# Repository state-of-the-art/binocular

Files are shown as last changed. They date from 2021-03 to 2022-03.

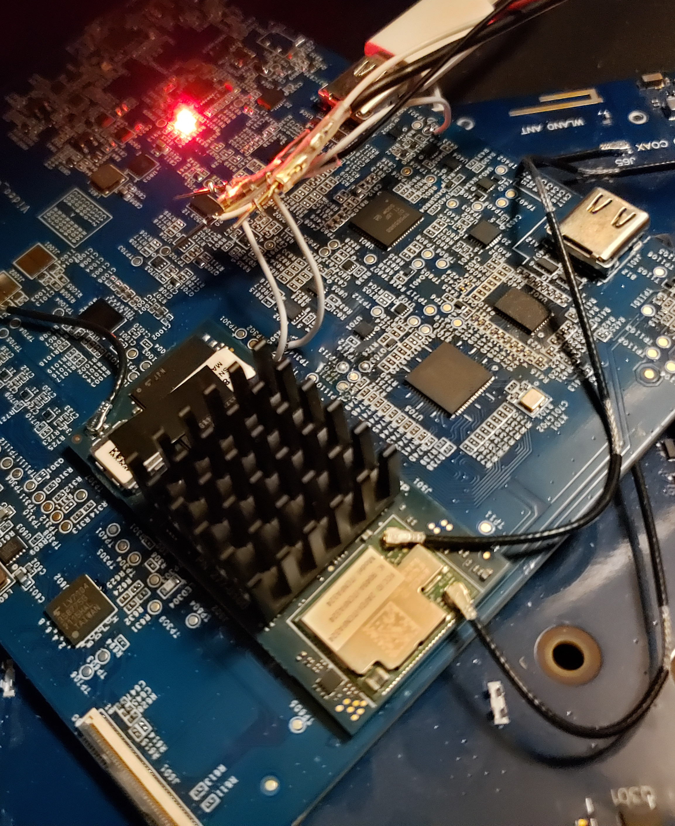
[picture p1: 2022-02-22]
design/prototype_1/pics/02_uart_boot_01_fail.jpg

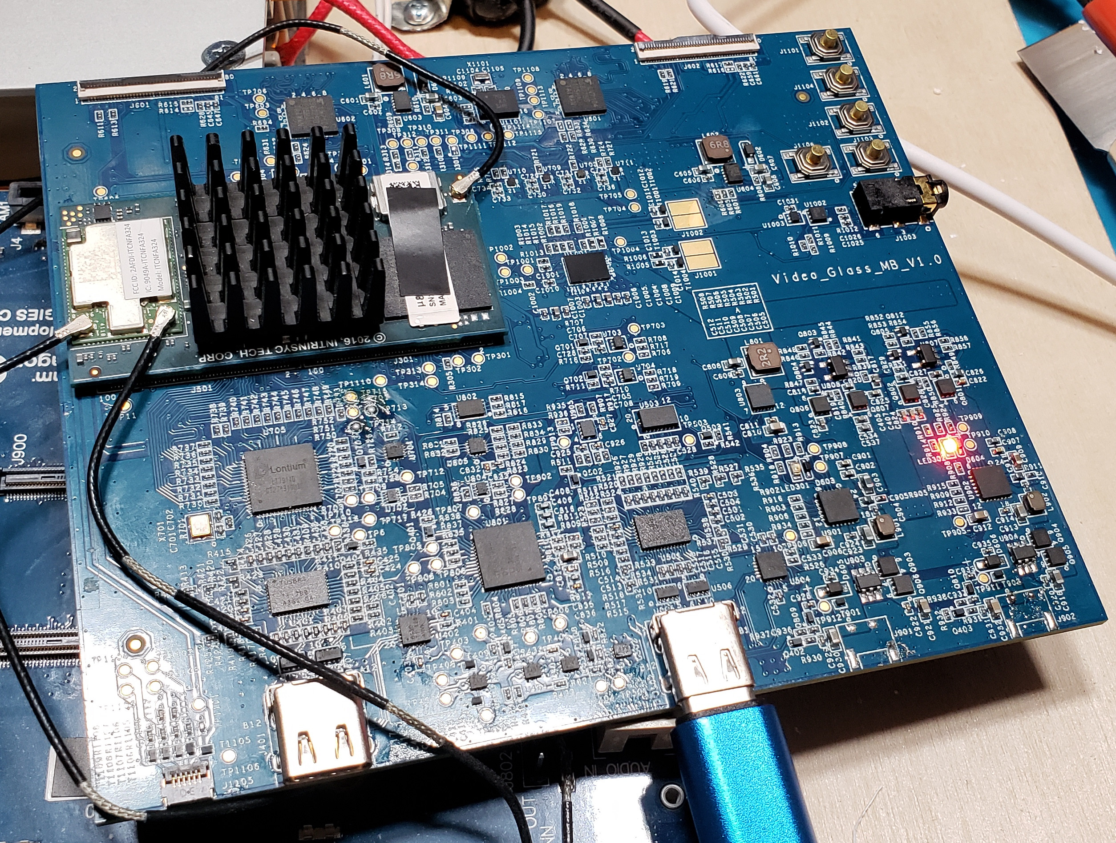
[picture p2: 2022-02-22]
design/prototype_1/pics/01_smoke_check.jpg

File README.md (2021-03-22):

# Binocular

Project aims to design the open hardware binocular wearing computer platform. It's PCB design and
the related software should be open to drive the development of VR/AR glasses for masses.

## Project Goal

To speedup the future come, where AR is a necessary part of the regular reality, like internet now.

## Designs

* [Prototype 1](design/prototype_1)

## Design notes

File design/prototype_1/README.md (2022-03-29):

# Prototype 1

The first prototype with the custom PCB design to fuse the SOM and modules together. Basically it
contains a number of buttons, leds, dual USB-C interface and a way to put SOM in place and connect
the displays.

## Requirements

1. Open Source and Open Hardware platform for light-weight wearable stereo displays as close as
currently possible to the regular glasses
2. No AR-grade positioning detection - just good quality high resolution see-through displays
(1920x1080)
3. Wireless (WiFi ac, h264/h265, battery power) and direct drive (USB-C DP alt-mode)

## Components

* [Platform](../../platform/snapdragon_820/open-q-u820/) - Open-Q µSOM 820
   * SOC - Snapdragon 820
* [Modules](../../modules/enmesi/r6) - Enmesi R6
  Birdbath (the best weight/quality ratio for now)
   * Displays - Sony ECX335S
* [PCB](pcb) - where SOM & Modules are met
* [Frame](frame) - TODO

## Documents

* [Design Document](Design Document.pdf)

## Configuring

In order to make Open-Q µSOM 820 work on the prototype - it should have a specific rpm partition
with modified LDO voltages. For this purpose it's better to get the original rpm partition from the
board, alter it's binary structure to write the required values into the special structure, resign
it and write back to the board.

To do that it's needed to have the original devboard for the prototype test board. Prototype release
will support protection for the used rails and will allow to flash any µSOM to the needed state.

**WARNING**: this is dangerous - writing the low-level partitions and especially altering them could
make your µSOM and devboard not bootable with common methods (only by EDL recovery), and the
operation we're going to do will make the µSOM not to work with devboard until the partition will
be restored. So you know - as is.

### Get with ADB

You can receive the rpm partition with root ADB.

1. Connect your devboard to power source
2. Connect the `USB2.0 (ADB)` to you host computer
3. Boot the devboard to android by pressing `ON/OFF` button
4. When the board boot-up switch the adbd to root mode and get the rpm partition this way:
   ```
   host $ adb root
   restarting adbd as root

   host $ adb shell cat /dev/block/by-name/rpm > rpm.img
   ```
5. And now you have the rpm partition image

### Modify the RPM partition

The voltages in the original RPM configuration is not suitable, so we need to reconfigure them.

1. Modify the `rpm.img` with [rpm_ldo_rail_tool.py](../../platform/snapdragon_820/tools/rpm_ldo_rail_tool.py):
   ```
   host $ platform/snapdragon_820/tools/rpm_ldo_rail_tool.py rpm.img
   Search for magic 00000000000000000a9001: 0x1000 0x2000 0x3000 0x4000 0x5000 0x6000 0x7000 0x8000 0x9000 0xa000 0xb000 0xc000 0xd000 0xe000 0xf000 0x10000 0x11000 0x12000 0x13000 0x14000 0x15000 0x16000 0x17000 0x18000 0x19000 0x1a000 0x1b000 0x1c000 0x1d000 0x1e000 0x1f000 0x20000 0x21000 0x22000 0x23000 0x24000 0x25000 0x26000 0x27000 0x28000 0x29000 0x2a000 0x2b000 0x2c000 0x2d000 0x2e000 0x2f000 0x30000 0x31000 0x32000 0x33000
   LDO struct was found on address 0x33098 processing...

   LDO14 raw: 0ac01202a406ea0b00000300
      Current Threshold: 10mA, Safety Headroom: 300mV
      Voltage Min: 1.700V
      Voltage Max: 3.050V
   LDO15 raw: 0ac012020807080700000300
      Current Threshold: 10mA, Safety Headroom: 300mV
    ! Voltage Min: 1.800V -> 1.200V
    ! Voltage Max: 1.800V -> 1.500V
   LDO17 raw: 0aa00f02c4098c0a00000300
      Current Threshold: 10mA, Safety Headroom: 250mV
    ! Voltage Min: 2.500V -> 1.750V
    ! Voltage Max: 2.700V -> 3.300V
   LDO18 raw: 0a800c028c0a540b00000200
      Current Threshold: 10mA, Safety Headroom: 200mV
    ! Voltage Min: 2.700V -> 1.800V
      Voltage Max: 2.900V
   LDO19 raw: 0a400602220b1c0c00000300
      Current Threshold: 10mA, Safety Headroom: 100mV
    ! Voltage Min: 2.850V -> 1.200V
    ! Voltage Max: 3.100V -> 1.500V
   LDO21 raw: 0ac012028c0a860b00000200
      Current Threshold: 10mA, Safety Headroom: 300mV
    ! Voltage Min: 2.700V -> 1.750V
    ! Voltage Max: 2.950V -> 3.300V
   LDO22 raw: 0ac01202d606e40c00000300
      Current Threshold: 10mA, Safety Headroom: 300mV
      Voltage Min: 1.750V
      Voltage Max: 3.300V
   LDO23 raw: 0a800c028c0a540b00000300
      Current Threshold: 10mA, Safety Headroom: 200mV
    ! Voltage Min: 2.700V -> 1.800V
      Voltage Max: 2.900V
   LDO29 raw: 05900102be0a220b00000300
      Current Threshold: 5mA, Safety Headroom: 25mV
    ! Voltage Min: 2.750V -> 1.750V
    ! Voltage Max: 2.850V -> 3.300V

   Result of modified rpm: rpm_mod.img
   Search complete
   ```
2. When you've get your `rpm_mod.img` - you need to sign it by [qtestsign](https://github.com/msm8916-mainline/qtestsign)
   ```
   host $ git clone https://github.com/msm8916-mainline/qtestsign
   Cloning into 'qtestsign'...
   remote: Enumerating objects: 17, done.
   remote: Counting objects: 100% (17/17), done.
   remote: Compressing objects: 100% (11/11), done.
   remote: Total 17 (delta 3), reused 17 (delta 3), pack-reused 0
   Unpacking objects: 100% (17/17), 16.64 KiB | 97.00 KiB/s, done.

   host $ cd qtestsign

   host $ python3 -m venv .venv

   host $ . .venv/bin/activate

   host $ pip install -r requirements.txt
   Collecting cryptography>=3.1
     Downloading cryptography-36.0.1-cp36-abi3-manylinux_2_17_x86_64.manylinux2014_x86_64.whl (3.8 MB
   )
        |████████████████████████████████| 3.8 MB 321 kB/s
   Collecting cffi>=1.12
     Downloading cffi-1.15.0-cp38-cp38-manylinux_2_12_x86_64.manylinux2010_x86_64.whl (446 kB)
        |████████████████████████████████| 446 kB 41.9 MB/s
   Collecting pycparser
     Downloading pycparser-2.21-py2.py3-none-any.whl (118 kB)
        |████████████████████████████████| 118 kB 35.8 MB/s
   Installing collected packages: pycparser, cffi, cryptography
   Successfully installed cffi-1.15.0 cryptography-36.0.1 pycparser-2.21

   host $ ./qtestsign.py rpm rpm_mod.img
   Before: Elf(ehdr=Ehdr(ei_magic=b'\x7fELF', ei_class=1, ei_data=1, ei_version=1, ei_os_abi=0, ei_abi_version=0, e_type=2, e_machine=40, e_version=1, e_entry=9, e_phoff=52, e_shoff=0, e_flags=83886082, e_ehsize=52, e_phentsize=32, e_phnum=4, e_shentsize=40, e_shnum=0, e_shstrndx=0), phdrs=[Phdr(p_type=0, p_offset=0, p_vaddr=0, p_paddr=0, p_filesz=180, p_memsz=0, p_flags=117440512, p_align=0), Phdr(p_type=0, p_offset=4096, p_vaddr=2752512, p_paddr=2752512, p_filesz=6568, p_memsz=8192, p_flags=35651584, p_align=4096), Phdr(p_type=1, p_offset=12288, p_vaddr=0, p_paddr=2097152, p_filesz=163472, p_memsz=163472, p_flags=2147483655, p_align=4), Phdr(p_type=1, p_offset=175760, p_vaddr=589824, p_paddr=2686976, p_filesz=53692, p_memsz=61884, p_flags=7, p_align=32)])
   Header(version=0, type=3, flash_addr=0, dest_addr=2752552, total_size=2432, hash_size=128, signature_addr=2752680, signature_size=256, cert_chain_addr=2752936, cert_chain_size=2048)
   After: Elf(ehdr=Ehdr(ei_magic=b'\x7fELF', ei_class=1, ei_data=1, ei_version=1, ei_os_abi=0, ei_abi_version=0, e_type=2, e_machine=40, e_version=1, e_entry=9, e_phoff=52, e_shoff=0, e_flags=83886082, e_ehsize=52, e_phentsize=32, e_phnum=4, e_shentsize=40, e_shnum=0, e_shstrndx=0), phdrs=[Phdr(p_type=0, p_offset=0, p_vaddr=0, p_paddr=0, p_filesz=180, p_memsz=0, p_flags=117440512, p_align=0),Phdr(p_type=0, p_offset=4096, p_vaddr=2752512, p_paddr=2752512, p_filesz=2472, p_memsz=4096, p_flags=35651584, p_align=4096), Phdr(p_type=1, p_offset=6568, p_vaddr=0, p_paddr=2097152, p_filesz=163472, p_memsz=163472, p_flags=2147483655, p_align=4), Phdr(p_type=1, p_offset=170048, p_vaddr=589824, p_paddr=2686976, p_filesz=53692, p_memsz=61884, p_flags=7, p_align=32)])
   ```
8. And now you have the modified and signed RPM for the binocular prototype - just need to flash it...

### Write with fastboot mode

Unfortunately fastboot doesn't provide a way to read the partition (fetch operation is not working),
but can help to write it back to the flash. After that you will need to dicsonnect your µSOM and
move it to the prototype board.

**WARNING:** after this operation you will not be able to boot the µSOM on Open-Q devboard until
you will restore the RPM partition to the original one. So make sure you have a backup of the
original rpm.img. The voltage changes should not fry your devboard, but better to not leave it on
the powered Open-Q devboard for a long time (precaution).

1. Disconnect the sensors expansion board (precaution)
2. Connect your devboard to power source
3. Connect the `USB2.0 (ADB)` to you host computer
4. Boot the devboard to fastboot mode by pressing `VOL (-)` and `ON/OFF` buttons together
5. Check the fastboot device connected properly:
   ```
   host $ fastboot devices
   277010101071910397      fastboot
   ```
6. Flash the modified RPM to the board
   ```
   host $ fastboot flash rpm rpm_mod-test-signed.mbn
   Sending 'rpm' (218 KB)                             OKAY [  0.037s]
   Writing 'rpm'                                      OKAY [  0.026s]
   Finished. Total time: 0.115s
   ```

### Using EDL mode

EDL mode is advanced recovery mode for Qualcomm SoC and needs some additional knowledge, but if you
want to dig in (or have no choice because your bootloader is not working well anymore) - welcome to
the special page about it: [EDL Mode](../../platform/snapdragon_820/open-q-u820/edl_mode.md)

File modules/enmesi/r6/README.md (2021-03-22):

# [Enmesi R6](http://www.enmesi.com/sale-13668784-oled-lvds-51-0-7in-micro-display-module-1080p-monocular.html)

* Product model: R6
* Display: Sony ECX335SN-6
   * Size: 0.7"
   * Resolution  1920x1080
   * Type: OLED
   * Colors: 24bit (16777K)
   * Frame Rate: 60Hz
* FOV: 51°
* Eyerelief: 15mm
* Eyebox: 8mm
* Distortion: 1.42%
* MTF: 0.15@30lp/mm
* Size: 18.5mm x 20.3mm
* Weight: 14g

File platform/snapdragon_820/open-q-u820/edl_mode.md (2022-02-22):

# EDL (QDL, QPST, QFIL) mode on Open-Q 820 Devboard

Emergency Download Mode is needed to recover your Qualcomm SoC in case your bootloader was broken.
This helped me to recovery from the incorrect `rpm` image flashing, so hopefully will help you too.

There is a number of ways to get into EDL mode, but here we will use the simplest one by USB cable.

## Requirements

* EDL cable (DIY)

## How to make EDL USB cable

To make it work - make sure you using the whole cable, not just the microusb head. The cable still
will serve you as regular USB cable, but with option to short the `Data+` line to ground.

There is multiple tutorials in the internet, so just the basic steps here:

1. Make sure the cable is actual USB-A to Micro-USB data cable, not just power one
2. Open the cable protection with knife along it's length
3. Find green and black wire and expose their copper wires
4. Solder a little button on the exposed wires - pressing will short GND and D+ lines
5. Use some glue or plastic to fixate the button on the cable

## Entering EDL mode for Open-Q 820 Devboard

1. Connect EDL cable to your host
2. Disable modem manager on your linux host: `sudo systemctl stop ModemManager`
3. Disconnect everything from the devboard
4. Find `S1` on the back side of the board and switch `USB Mode Select` to `ON` - this will enable
USB1 RECOVERY port and disable USB3 HOST ports on the devboard.
5. Put power cord in the dev board
6. Connect Debug UART USB and run minicom to monitor the boot process
7. Holding the button on the cable (GND and D+ shorted) connect microusb to the `USB1 RECOVERY` on
the devboard
8. When the devboard booted release the button on the cable and you will see that the host
recognized the new USB device with `idVendor=05c6` and `idProduct=9008` - it's your EDL

## Getting the EDL app

To use EDL we need a special application to interact with sahara protocol to upload the firehose
binary and make it do what we want. For that we will use edl from https://github.com/bkerler/edl

Just clone the repository: `git clone https://github.com/bkerler/edl` and follow the installation
procedures in the README file.

## Using EDL

The most important options is the `loader` and `skipresponse`:
* Loader is the firehose binary which is loaded to the memory to provide you interface to
interact with the resources on the board. We will take the built-in loader for our msm8996 platform.
* Skipresponse is needed, because for some reason the firehose doesn't response properly - so put
this option to make it work, otherwise edl will hang or drop into you some weird errors.

Not all the loaders will work well for you, for example to properly read the info I used
`qualcomm/model_generic/msm8996/0000000000000000_b53fb23d1953decb_fhprg_peek.bin`, but I found it's
incapable to write data (it takes a long time and when you read after write it's not changed). So
for write I had to switch to another firehose `Loaders/xiaomi/009470e100000000_355d47f912fea0af_fhprg_peek.bin`
and to make it work a bit alter the logic of edl to skip the weird bug during configure operation:
https://github.com/bkerler/edl/issues/238

### Getting info from the board

There is a couple of commands to get the useful information from the board, regarding storage and
overall system. Just execute something like:
```
$ edl printgpt --lun 4 --memory UFS --skipresponse --loader Loaders/qualcomm/model_generic/msm8996/0000000000000000_b53fb23d1953decb_fhprg_peek.bin
Qualcomm Sahara / Firehose Client V3.60 (c) B.Kerler 2018-2022.
main - Using loader Loaders/qualcomm/model_generic/msm8996/0000000000000000_b53fb23d1953decb_fhprg_peek.bin ...
main - Waiting for the device
main - Device detected :)
main - Mode detected: firehose
main - Trying to connect to firehose loader ...
firehose - fh.attrs.Verbose is set to 0
firehose - Chip serial num: 727671321 (0x2b5f6219)
firehose - Supported Functions: program configure nop firmwarewrite patch setbootablestoragedrive ufs emmc readIMEI writeIMEI simlock power benchmark read eMMCinfo getstorageinfo getsha256digest e
rase peek poke
firehose - TargetName=MSM8996
firehose - MemoryName=UFS
firehose - Version=2
firehose - Trying to read first storage sector...
firehose - Running configure...
firehose - {'Device Total Logical Blocks': '0x60ac00', 'Device Block Size in Bytes': '0x1000', 'Device Total Physical Paritions': '0x6', 'Device Manufacturer ID': '0x198', 'Device Serial Number':
'0x0', 'UFS fInitialized': '0x1', 'UFS Current LUN Number: ': ' 0xd0', 'UFS Total Active LU': '0x6', 'UFS wManufacturerID': '0x198', 'UFS Boot Partition Enabled': '0x1', 'UFS Raw Device Capacity:
': ' 0x3b9e000', 'UFS Min Block Size': '0x8', 'UFS Erase Block Size': '0x2000', 'UFS Allocation Unit Size': '0x1', 'UFS RPMB ReadWrite Size: ': ' 0x40', 'UFS Number of Allocation Uint for This LU'
: '0x0', 'UFS Logical Block Size': '0x0', 'UFS Provisioning Type': '0x0', 'UFS LU Write Protect': '0x0', 'UFS Boot LUN ID: ': ' 0x0', 'UFS Memory Type': '0x0', 'UFS LU Total Blocks': '0x0', 'UFS S
upported Memory Types': '0x801f', 'UFS dEnhanced1MaxNAllocU': '0x1dcf', 'UFS wEnhanced1CapAdjFac': '0x200', 'UFS dEnhanced2MaxNAllocU: ': ' 0x20', 'UFS wEnhanced2CapAdjFac': '0x200', 'UFS dEnhance
d3MaxNAllocU': '0x0', 'UFS wEnhanced3CapAdjFac': '0x0', 'UFS dEnhanced4MaxNAllocU': '0x0', 'UFS wEnhanced4CapAdjFac': '0x0', 'UFS LUN Enable Bitmask': '0x3f', 'UFS Logical Block Count': '0x0', 'UF
S bConfigDescrLock': '0x0', 'UFS iManufacturerName String Index': '0x1', 'UFS iProductName String Index': '0x2', 'UFS iSerialNumber String Index': '0x3', 'UFS iOemID String Index': '0x4', 'UFS Inq
uiry Command Output': 'TOSHIBA THGAF4G8N2LBAIRB0100 '}
firehose - {'Device Total Logical Blocks': '0x60ac00', 'Device Block Size in Bytes': '0x1000', 'Device Total Physical Paritions': '0x6', 'Device Manufacturer ID': '0x198', 'Device Serial Number':
'0x0', 'UFS fInitialized': '0x1', 'UFS Current LUN Number: ': ' 0xd0', 'UFS Total Active LU': '0x6', 'UFS wManufacturerID': '0x198', 'UFS Boot Partition Enabled': '0x1', 'UFS Raw Device Capacity:
': ' 0x3b9e000', 'UFS Min Block Size': '0x8', 'UFS Erase Block Size': '0x2000', 'UFS Allocation Unit Size': '0x1', 'UFS RPMB ReadWrite Size: ': ' 0x40', 'UFS Number of Allocation Uint for This LU'
: '0x0', 'UFS Logical Block Size': '0x0', 'UFS Provisioning Type': '0x0', 'UFS LU Write Protect': '0x0', 'UFS Boot LUN ID: ': ' 0x0', 'UFS Memory Type': '0x0', 'UFS LU Total Blocks': '0x0', 'UFS S
upported Memory Types': '0x801f', 'UFS dEnhanced1MaxNAllocU': '0x1dcf', 'UFS wEnhanced1CapAdjFac': '0x200', 'UFS dEnhanced2MaxNAllocU: ': ' 0x20', 'UFS wEnhanced2CapAdjFac': '0x200', 'UFS dEnhance
d3MaxNAllocU': '0x0', 'UFS wEnhanced3CapAdjFac': '0x0', 'UFS dEnhanced4MaxNAllocU': '0x0', 'UFS wEnhanced4CapAdjFac': '0x0', 'UFS LUN Enable Bitmask': '0x3f', 'UFS Logical Block Count': '0x0', 'UF
S bConfigDescrLock': '0x0', 'UFS iManufacturerName String Index': '0x1', 'UFS iProductName String Index': '0x2', 'UFS iSerialNumber String Index': '0x3', 'UFS iOemID String Index': '0x4', 'UFS Inq
uiry Command Output': 'TOSHIBA THGAF4G8N2LBAIRB0100 '}
firehose - 0x1
firehose_client - Supported functions:
-----------------
program,configure,nop,firmwarewrite,patch,setbootablestoragedrive,ufs,emmc,readIMEI,writeIMEI,simlock,power,benchmark,read,eMMCinfo,getstorageinfo,getsha256digest,erase,peek,poke

Parsing Lun 4:

GPT Table:
-------------
rpm:                 Offset 0x0000000000006000, Length 0x0000000000080000, Flags 0x1000000000000000, UUID a16bac30-1326-f6ca-8e7c-2faaca32da99, Type 0x98df793, Active False
rpmbak:              Offset 0x0000000000086000, Length 0x0000000000080000, Flags 0x1000000000000000, UUID d8829e88-9b2a-d439-1eac-6609dcf0b2c1, Type 0x98df793, Active False
tz:                  Offset 0x0000000000106000, Length 0x0000000000200000, Flags 0x1000000000000000, UUID 61f7bf05-ab56-e6bc-bb8b-46f59e1ecebc, Type 0xa053aa7f, Active False
tzbak:               Offset 0x0000000000306000, Length 0x0000000000200000, Flags 0x1000000000000000, UUID 8d301041-498d-3b85-1329-80b3cc3d0703, Type 0xa053aa7f, Active False
hyp:                 Offset 0x0000000000506000, Length 0x0000000000080000, Flags 0x1000000000000000, UUID bc3c61eb-95cc-4035-dd09-f92756537f46, Type 0xe1a6a689, Active False
hypbak:              Offset 0x0000000000586000, Length 0x0000000000080000, Flags 0x1000000000000000, UUID 5830e1b7-b7ad-0bb4-99f6-d803216013a0, Type 0xe1a6a689, Active False
fsg:                 Offset 0x0000000000606000, Length 0x0000000000200000, Flags 0x1000000000000000, UUID 8cbe317e-dbb3-db04-b7cf-516a5b2ee92a, Type 0x638ff8e2, Active False
sec:                 Offset 0x0000000000806000, Length 0x0000000000004000, Flags 0x1000000000000000, UUID 1548cb91-5b77-48f7-08e7-20e7c6bcadbb, Type 0x303e6ac3, Active False
pmic:                Offset 0x000000000080a000, Length 0x0000000000080000, Flags 0x1000000000000000, UUID 53e1ea64-dab9-3542-b7b4-1b935aabb203, Type 0xc00eef24, Active False
pmicbak:             Offset 0x000000000088a000, Length 0x0000000000080000, Flags 0x1000000000000000, UUID 8927eacf-79ac-a277-afcd-c5207699b2ec, Type 0xc00eef24, Active False
modem:               Offset 0x000000000090a000, Length 0x0000000005f00000, Flags 0x1000000000000000, UUID 6068c262-35f4-e794-86e3-008b74f19a38, Type EFI_BASIC_DATA, Active False
dsp:                 Offset 0x000000000680a000, Length 0x0000000001000000, Flags 0x1000000000000000, UUID 83ca8a0d-6e04-626f-69f9-cffd8fa2f59e, Type 0x7efe5010, Active False
dip:                 Offset 0x000000000780a000, Length 0x0000000000100000, Flags 0x1000000000000000, UUID e9565799-03db-8a15-5f18-d294b672a990, Type 0x4114b077, Active False
mdtp:                Offset 0x000000000790a000, Length 0x0000000002000000, Flags 0x1000000000000000, UUID c1093cf0-8517-627a-0ba9-3a244fa56a0c, Type 0x3878408a, Active False
aboot:               Offset 0x000000000990a000, Length 0x0000000000100000, Flags 0x1000000000000000, UUID dcd49fc3-dea6-6d20-30a9-069b65d0935d, Type 0x400ffdcd, Active False
abootbak:            Offset 0x0000000009a0a000, Length 0x0000000000100000, Flags 0x1000000000000000, UUID f1491067-00d8-31a0-79c5-d8305c14536b, Type 0x400ffdcd, Active False
boot:                Offset 0x0000000009b0a000, Length 0x0000000004000000, Flags 0x1000000000000000, UUID 0be2bf76-7058-ae79-9edc-e304f3a51bdb, Type 0x20117f86, Active False
system:              Offset 0x000000000db0a000, Length 0x00000000c0000000, Flags 0x1000000000000000, UUID 1533f726-c278-52fe-fa75-9e5dbcc1de5b, Type 0x97d7b011, Active False
recovery:            Offset 0x00000000cdb0a000, Length 0x0000000004000000, Flags 0x1000000000000000, UUID 0cb57bbe-e391-c70f-4ec2-82e5c0c8f41d, Type 0x9d72d4e4, Active False
devinfo:             Offset 0x00000000d1b0a000, Length 0x0000000000001000, Flags 0x1000000000000000, UUID d2457b35-aff9-7485-2b15-af48ae9cc5f6, Type 0x65addcf4, Active False
bluetooth:           Offset 0x00000000d1b0b000, Length 0x0000000000100000, Flags 0x1000000000000000, UUID 57148a79-9018-2330-3796-19ace13d7c5a, Type 0x6cb747f1, Active False
keymaster:           Offset 0x00000000d1c0b000, Length 0x0000000000080000, Flags 0x1000000000000000, UUID 4fcd6677-e89a-ec9d-b7a9-627110c320e6, Type 0x4f772165, Active False
keymasterbak:        Offset 0x00000000d1c8b000, Length 0x0000000000080000, Flags 0x1000000000000000, UUID ca67fe2b-5baa-7d25-1ce1-e8814a1dae09, Type 0x4f772165, Active False
cmnlib:              Offset 0x00000000d1d0b000, Length 0x0000000000080000, Flags 0x1000000000000000, UUID 087a42b0-6f63-5ddd-b9ca-8ae0e81804c9, Type 0x73471795, Active False
cmnlibbak:           Offset 0x00000000d1d8b000, Length 0x0000000000080000, Flags 0x1000000000000000, UUID 29583d61-fffe-bfc5-0b74-81e97a36a8fc, Type 0x73471795, Active False
cmnlib64:            Offset 0x00000000d1e0b000, Length 0x0000000000080000, Flags 0x1000000000000000, UUID 251fda90-4a4d-98ae-cff8-af6cd4da0413, Type 0x8ea64893, Active False
cmnlib64bak:         Offset 0x00000000d1e8b000, Length 0x0000000000080000, Flags 0x1000000000000000, UUID f3ef7361-108e-d461-2267-d1ab9dc20a9c, Type 0x8ea64893, Active False
apdp:                Offset 0x00000000d1f0b000, Length 0x0000000000040000, Flags 0x1000000000000000, UUID e25118df-f580-35d6-3f5c-0e2e72498847, Type 0xe6e98da2, Active False
msadp:               Offset 0x00000000d1f4b000, Length 0x0000000000040000, Flags 0x1000000000000000, UUID db3f36c3-18cc-f14c-3a81-0ff9ea5d2535, Type 0xed9e8101, Active False
dpo:                 Offset 0x00000000d1f8b000, Length 0x0000000000001000, Flags 0x1000000000000000, UUID 36ca4436-1a62-e040-fefc-1e1b3a02c3ef, Type 0x11406f35, Active False
splash:              Offset 0x00000000d1f8c000, Length 0x00000000020a4000, Flags 0x1000000000000000, UUID bf92587b-66e1-a141-5c5b-051b03daa7ec, Type 0xad99f201, Active False
sti:                 Offset 0x00000000d4030000, Length 0x0000000000200000, Flags 0x0000000000000000, UUID ab89e120-3cfc-3914-e9ca-2449fe786f6a, Type 0xaa9a5c4c, Active False

Total disk size:0x000000010001c000, sectors:0x000000000010001c
```

### Dump the entire storage

```
$ edl rf storage.img --memory UFS --skipresponse --loader Loaders/qualcomm/model_generic/msm8996/0000000000000000_b53fb23d1953decb_fhprg_peek.bin
...
firehose_client - Supported functions:
-----------------
program,configure,nop,firmwarewrite,patch,setbootablestoragedrive,ufs,emmc,readIMEI,writeIMEI,simlock,power,benchmark,read,eMMCinfo,getstorageinfo,getsha256digest,erase,peek,poke
Dumping lun 0 with sector count 6335516 as out.flash.
firehose -
Reading from physical partition 0, sector 0, sectors 6335516
Progress: |█████████-----------------------------------------|  18.0% Read (Sector 0x115D00 of 0x60AC1C, 57m:54s left) 5.83 MB/s
```

### Flash partition

In case you just need to write one partition (to restore it or change a bit) - you can use the next
command (writing `rpmbak.img` file to the `rpm` partition):

(NOTE: if you see the partition is now wrtiting quickly - means you have a wrong firehose or
the write auth is required. First of all check `getstorageinfo` command "UFS LU Write Protect" flag
and try the other firehoses for your SoC before panic.)

```
$ edl w rpm rpmbak.img  --memory UFS --loader Loaders/xiaomi/009470e100000000_355d47f912fea0af_fhprg_peek.bin
Qualcomm Sahara / Firehose Client V3.60 (c) B.Kerler 2018-2022.
main - Using loader Loaders/xiaomi/009470e100000000_355d47f912fea0af_fhprg_peek.bin ...
main - Waiting for the device
main - Device detected :)
sahara - Protocol version: 2.1
main - Mode detected: sahara
sahara -
------------------------
HWID:              0x0003e0e100000000 (MSM_ID:0x0003e0e1,OEM_ID:0x0000,MODEL_ID:0x0000)
Unknown CPU, please send log as issue to https://github.com/bkerler/edl
PK_HASH:           0x7be49b72f9e4337223ccb84d6eccca4e61ce16e3602ac2008cb18b75babe6d09
Serial:            0x2b5f6219

sahara - Protocol version: 2.1
sahara - Uploading loader Loaders/xiaomi/009470e100000000_355d47f912fea0af_fhprg_peek.bin ...
sahara - 64-Bit mode detected.
sahara - Firehose mode detected, uploading...
sahara - Loader successfully uploaded.
main - Trying to connect to firehose loader ...
firehose
firehose - [LIB]: !DEBUG! rsp.data: 'bytearray(b'<?xml version="1.0" encoding="UTF-8" ?>\n<data>\n<log value="Binary build date: Feb 27 2016 @ 21:09:42"/>\n</data><?xml version="1.0" encoding="UTF-8" ?>\n<data>\n<log value="Chip serial num: 727671321 (0x2b5f6219)"/>\n</data><?xml version="1.0" encoding="UTF-8" ?>\n<data>\n<log value="Supported Functions: program configure nop firmwarewrite patch setbootablestoragedrive ufs emmc power benchmark read getstorageinfo getsha256digest erase peek poke "/>\n</data><?xml version="1.0" encoding="UTF-8" ?>\n<data>\n<log value="ufs 198,3b9e000"/>\n</data>')'
firehose - TargetName=MSM8996
firehose - MemoryName=UFS
firehose - Version=1
firehose - Trying to read first storage sector...
firehose - Running configure...
firehose - {'Device Total Logical Blocks': '0x60ac00', 'Device Block Size in Bytes': '0x1000', 'Device Total Physical Paritions': '0x6', 'Device Manufacturer ID': '0x198', 'Device Serial Number': '0x0', 'UFS fInitialized': '0x1', 'UFS Current LUN Number: ': ' 0xd0', 'UFS Total Active LU': '0x6', 'UFS wManufacturerID': '0x198', 'UFS Boot Partition Enabled': '0x1', 'UFS Raw Device Capacity: ': ' 0x3b9e000', 'UFS Min Block Size': '0x8', 'UFS Erase Block Size': '0x2000', 'UFS Allocation Unit Size': '0x1', 'UFS RPMB ReadWrite Size: ': ' 0x40', 'UFS Number of Allocation Uint for This LU': '0x0', 'UFS Logical Block Size': '0x0', 'UFS Provisioning Type': '0x0', 'UFS LU Write Protect': '0x0', 'UFS Boot LUN ID: ': ' 0x0', 'UFS Memory Type': '0x0', 'UFS LU Total Blocks': '0x0', 'UFS Supported Memory Types': '0x801f', 'UFS dEnhanced1MaxNAllocU': '0x1dcf', 'UFS wEnhanced1CapAdjFac': '0x200', 'UFS dEnhanced2MaxNAllocU: ': ' 0x20', 'UFS wEnhanced2CapAdjFac': '0x200', 'UFS dEnhanced3MaxNAllocU': '0x0', 'UFS wEnhanced3CapAdjFac': '0x0', 'UFS dEnhanced4MaxNAllocU': '0x0', 'UFS wEnhanced4CapAdjFac': '0x0', 'UFS LUN Enable Bitmask': '0x3f', 'UFS Logical Block Count': '0x0', 'UFS bConfigDescrLock': '0x0', 'UFS iManufacturerName String Index': '0x1', 'UFS iProductName String Index': '0x2', 'UFS iSerialNumber String Index': '0x3', 'UFS iOemID String Index': '0x4', 'UFS Inquiry Command Output': 'TOSHIBA THGAF4G8N2LBAIRB0100 '}
firehose - {'Device Total Logical Blocks': '0x60ac00', 'Device Block Size in Bytes': '0x1000', 'Device Total Physical Paritions': '0x6', 'Device Manufacturer ID': '0x198', 'Device Serial Number': '0x0', 'UFS fInitialized': '0x1', 'UFS Current LUN Number: ': ' 0xd0', 'UFS Total Active LU': '0x6', 'UFS wManufacturerID': '0x198', 'UFS Boot Partition Enabled': '0x1', 'UFS Raw Device Capacity: ': ' 0x3b9e000', 'UFS Min Block Size': '0x8', 'UFS Erase Block Size': '0x2000', 'UFS Allocation Unit Size': '0x1', 'UFS RPMB ReadWrite Size: ': ' 0x40', 'UFS Number of Allocation Uint for This LU': '0x0', 'UFS Logical Block Size': '0x0', 'UFS Provisioning Type': '0x0', 'UFS LU Write Protect': '0x0', 'UFS Boot LUN ID: ': ' 0x0', 'UFS Memory Type': '0x0', 'UFS LU Total Blocks': '0x0', 'UFS Supported Memory Types': '0x801f', 'UFS dEnhanced1MaxNAllocU': '0x1dcf', 'UFS wEnhanced1CapAdjFac': '0x200', 'UFS dEnhanced2MaxNAllocU: ': ' 0x20', 'UFS wEnhanced2CapAdjFac': '0x200', 'UFS dEnhanced3MaxNAllocU': '0x0', 'UFS wEnhanced3CapAdjFac': '0x0', 'UFS dEnhanced4MaxNAllocU': '0x0', 'UFS wEnhanced4CapAdjFac': '0x0', 'UFS LUN Enable Bitmask': '0x3f', 'UFS Logical Block Count': '0x0', 'UFS bConfigDescrLock': '0x0', 'UFS iManufacturerName String Index': '0x1', 'UFS iProductName String Index': '0x2', 'UFS iSerialNumber String Index': '0x3', 'UFS iOemID String Index': '0x4', 'UFS Inquiry Command Output': 'TOSHIBA THGAF4G8N2LBAIRB0100 '}
firehose - 0x1
firehose_client - Supported functions:
-----------------
firehose -
Writing to physical partition 4, sector 6, sectors 128
Progress: |██████████████████████████████████████████████████| 100.0% Write (Sector 0x80 of 0x80, ) 7.04 MB/s
Wrote rpmbak.img to sector 6.
```

## Useful docs

* https://web.archive.org/web/20220107093520/https://alephsecurity.com/2018/01/22/qualcomm-edl-1/
* https://www.96boards.org/documentation/consumer/dragonboard/dragonboard820c/installation/board-recovery.md.html
* https://www.96boards.org/documentation/consumer/guides/qdl.md.html
* JTAG pinout: https://www.manualslib.com/manual/1299111/Intrinsyc-Open-Q-835.html?page=26
* https://forum.xda-developers.com/t/guide-how-to-dump-and-write-back-the-storage-on-most-of-qualcomm-devices.3949588/

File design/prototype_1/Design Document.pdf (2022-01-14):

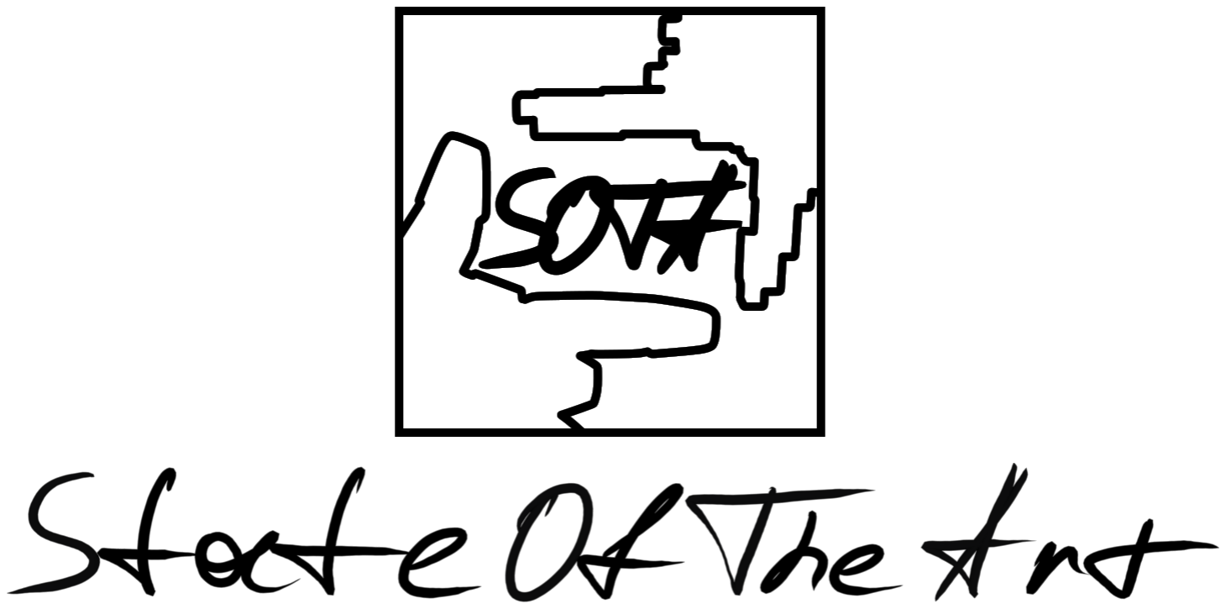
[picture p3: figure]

# PDD: Binocular prototype

State Of The Art LLC

Revision: 0.99
Date: 2020-12-24

# Project main ideas

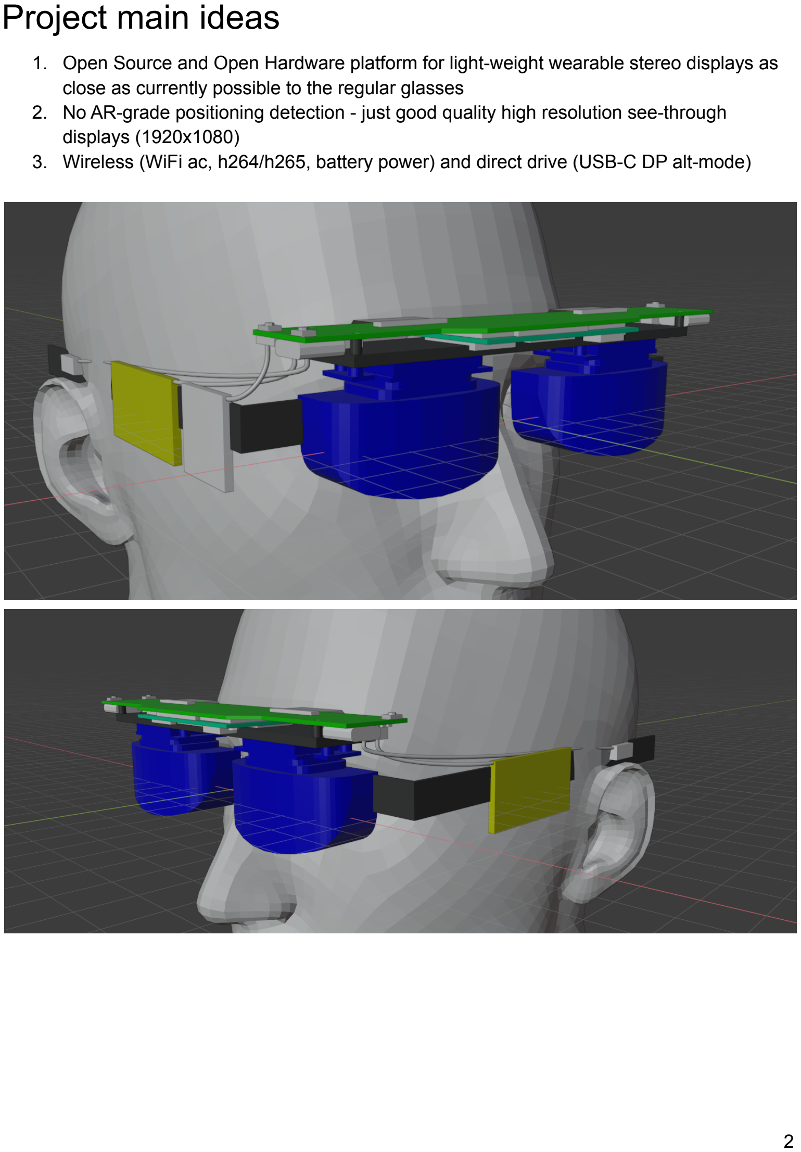
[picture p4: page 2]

1. Open Source and Open Hardware platform for light-weight wearable stereo displays as close as currently possible to the regular glasses
2. No AR-grade positioning detection - just good quality high resolution see-through displays (1920x1080)
3. Wireless (WiFi ac, h264/h265, battery power) and direct drive (USB-C DP alt-mode)

# Features list

- Play media:
- See-through modules with 1080p modules capable to show screen right in front of the eyes in mono and stereo mode
- “USB-C Left” functionality:
■ Power Delivery 2.0 (charge)
■ DP1.2 HBR2 Alt-mode input, 4 lanes - 4x5.40Gbit/s:
- 1920x1080@60Hz (3.20 Gbit/s) - fullhd mono default
- 3840x1080@60Hz (2x3.20 Gbit/s) - fullhd stereo
- 2560x1440@60Hz (5.63 Gbit/s) - 2k mono
- 5120x1440@60Hz (2x5.63 Gbit/s) - 2k stereo
- 3840x2160@60Hz (12.54 Gbit/s) - 4k mono
■ USB2 OTG (using USB-C D+/D- pins)
- “USB-C Right” functionality:
■ Power Delivery 2.0 (charge)
■ Switch:
- USB2/3 OTG (5GBit/s + 480MBit/s)
- HDMI 2.0 Alt-mode output
- Network video streaming (WiFi):
■ HTTP REST API for simple control of the device (playback/switches/profiles...)
■ RTSP/RTMP stream interfaces (send stream)
■ Miracast support
- Play video from built-in flash (32GB) or connected usb flash device
- HUD overlay mixed with video (SoC receives and sends video to displays)
- Audio input:
■ From DP (LT7911B through I2S to SoC), stream or file
- Audio output:
■ Bluetooth to connect audio devices
■ 2.5mm TRRS jack for headset (stereo+mic)
■ Built-in bone-conductive drivers (GD06) (https://www.aliexpress.com/item/32966655725.html)
■ HDMI Audio output
- Common Android device features:
- Autonomous work of the most power-consuming use case for >= 2 hours
- A couple of buttons to quickly access the important things:
■ volume +/- (android system master output volume)
■ power/sleep
■ home android button
■ back android button
- Touchpad for precision control (similar to GearVR) (https://images-na.ssl-images-amazon.com/images/I/619VY7CqqkL._AC_SL1500_.jpg)
- Run any applications available for Android ecosystem
- Bluetooth input devices (mouse, keyboard, any HID)
- USB-C modes:

■ Power Delivery - power & charge
■ OTG mode (usb-flash, input, cameras, ethernet...) with power 1-2A 5V of ext devices
■ ADB/Fastboot interfaces support
■ Drive external display via DP Alt-mode
- Accel/Gyro/Mag - IMU for simple head control gestures

# Common use cases

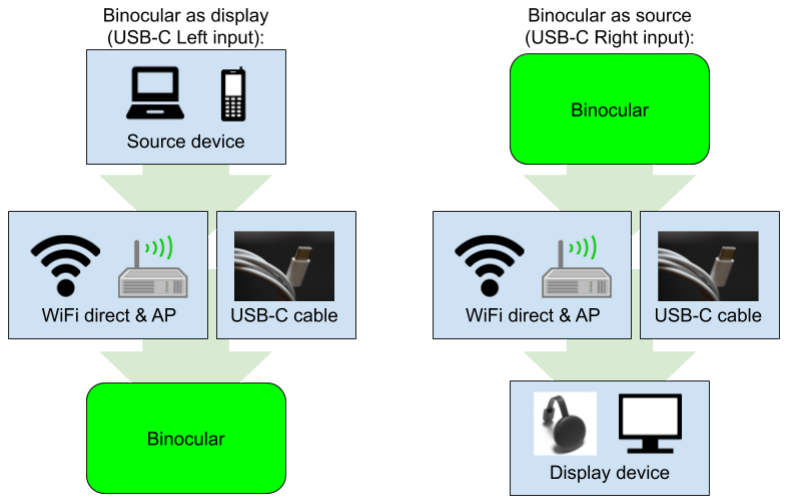
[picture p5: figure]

The binocular device could be used as display (receive DP and act as display) or as a source (if connected via USB-C to display). 2 USB-C connectors can be used simultaneously, but the right one can serve one mode at a time: USB2/3 OTG or HDMI.

- User power-on the device
- Android boots up
- Monitoring daemons starting up (check the connected devices and chooses the action to execute)
- Network daemons starting up (listens on TCP/UDP ports for incoming connections on HTTP/RTP/RTMP and other supported protocols)
- ?WiFi AP mode enabled (default)
■ WiFi AP announces and wait for incoming connections
- ?WiFi has saved connections
■ Scan around and connect to SSID if it’s available
- Bluetooth announces device and waits for incoming connections ■ ? Bluetooth paired devices available
- Connect paired device
- User connects the device to notebook via “USB-C Left”
- PD Power + Charge
- ? Device in fastboot mode
■ Fastboot

- ? DP Alt-mode is enabled (default)
■ Daemon on android starts to show the display via built-in application
- ? User choose mono
- 1920x1080@60
- ? User choose stereo
- 3840x1080@60
- ? App has HUD enabled
- shows video as HUD profile is configured
- ? ADB enabled
■ Working as regular ADB android device (root enabled)
- Device connected to USB-C monitor via “USB-C Right”
- PD Power + Charge
- ? Mirror display mode enabled (default)
■ Mirroring the MIPI DSI output to external monitor
- ? Additional display mode enabled
■ Connect ext monitor as another display
- Device connected to regular USB3 port
- PD Power + Charge
- Device acts as USB3 device
- Device connected to USB2/3 mass-storage device
- Power supply for connected device
- Mount device as additional storage

# PCB board

Will be placed on top of the modules, there is not much of space to place the components & connectors. So the dimensions should be 130x25x1mm.

PCB design should be available in open source formats (KiCAD for example). They can be developed in any software and converted to those formats in order to generate output files for manufacturing. That means that the pipeline should prove the ability to regenerate the gerber files from open source tools (for example Eagle -> KiCAD -> Gerber files).

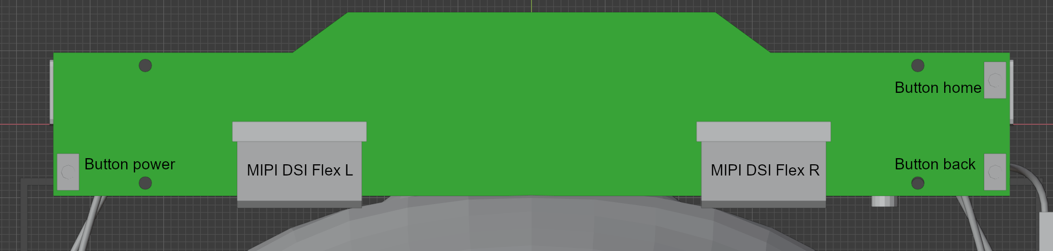
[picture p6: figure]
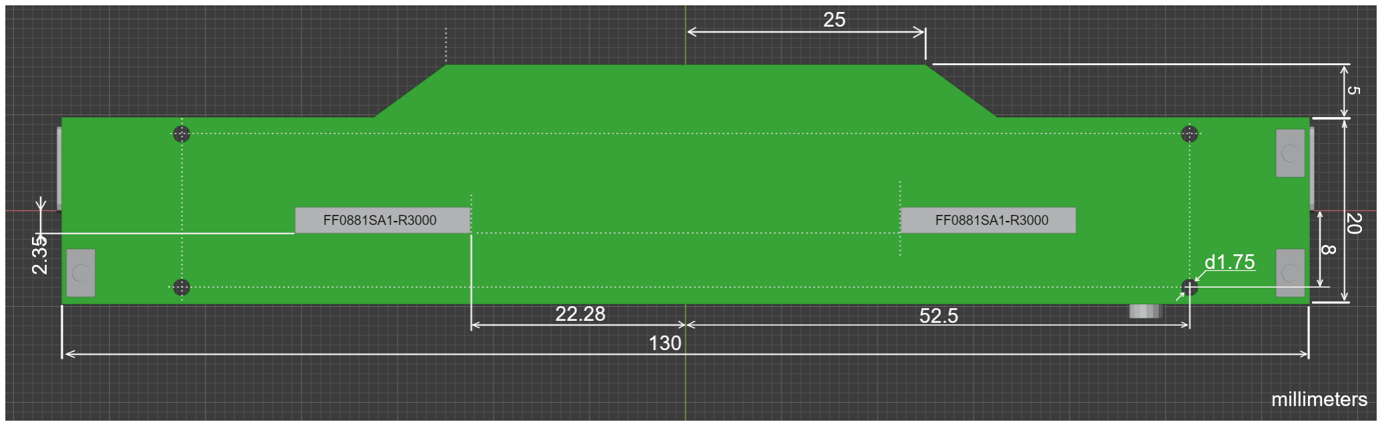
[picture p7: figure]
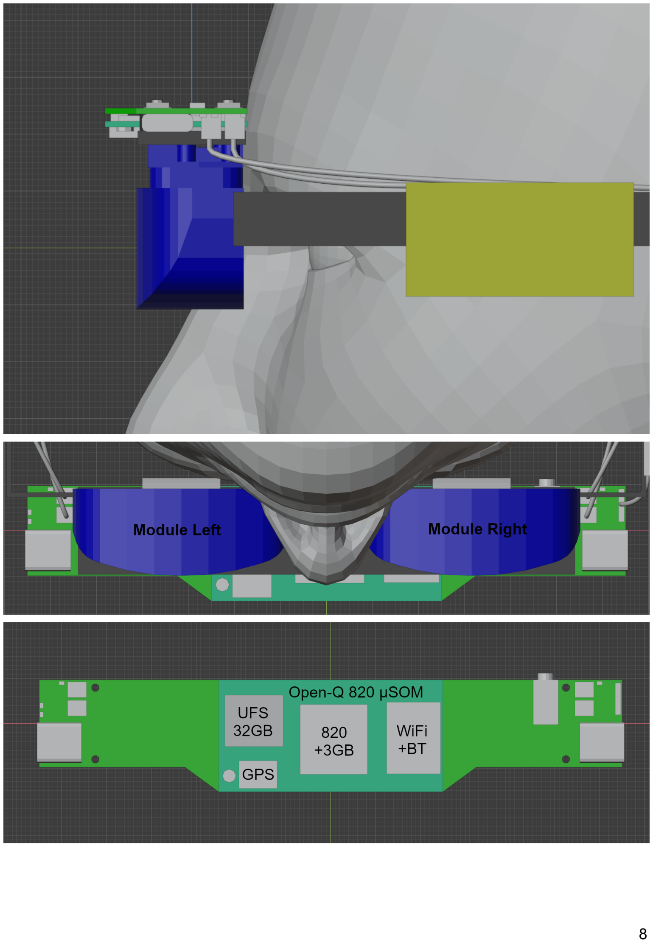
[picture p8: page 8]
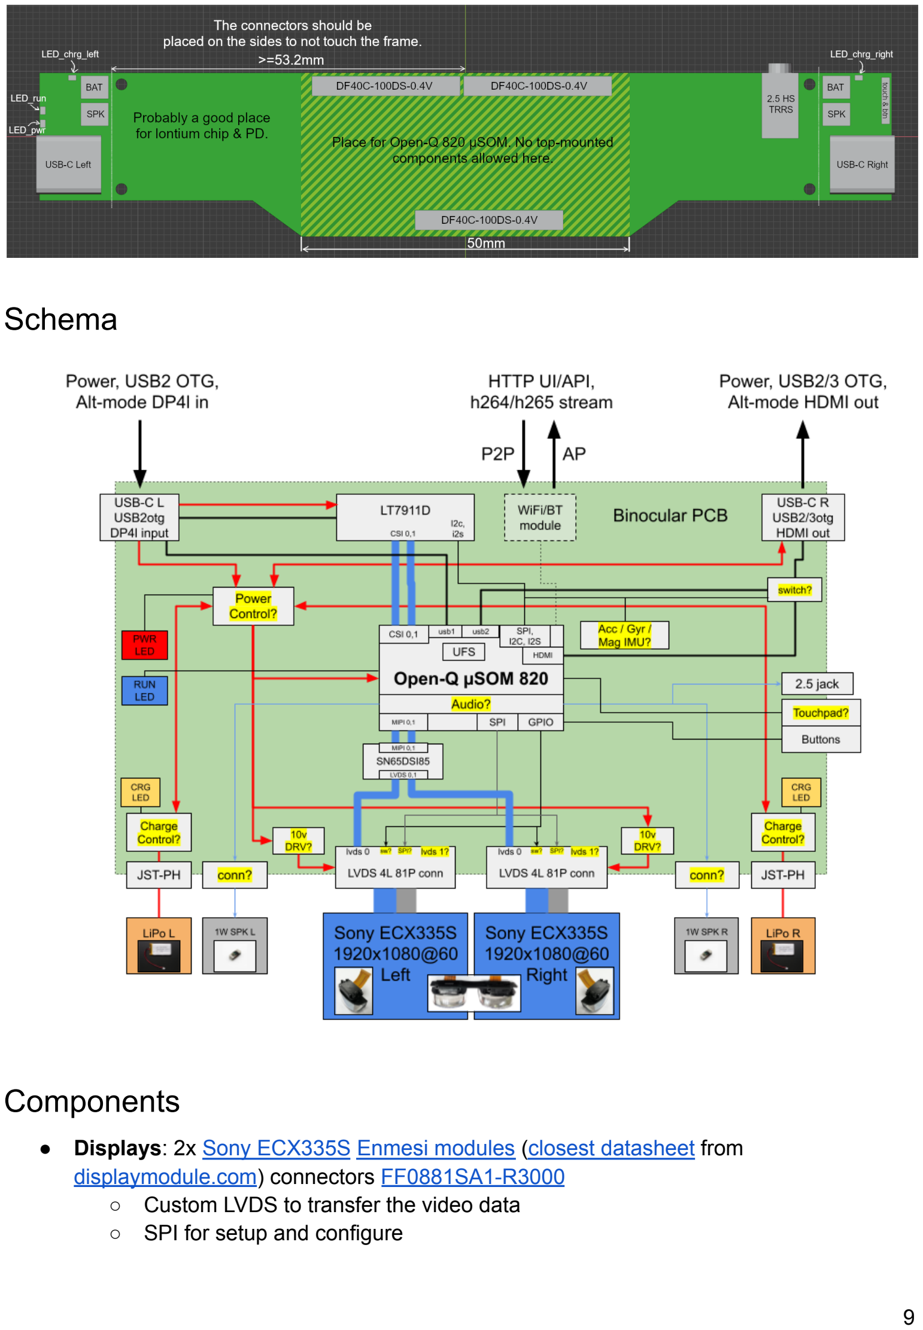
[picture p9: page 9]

## Schema

## Components

- Displays: 2x Sony ECX335S (https://www.sony-semicon.co.jp/e/products/microdisplay/oled/product.html) Enmesi modules (http://www.enmesi.com/sale-12414834-durable-tft-lcd-display-module-0-7-transparens-oled-screen-1920-1080-high-resolution.html) (closest datasheet (https://drive.google.com/file/d/1qSqLeB327I37T0W1lWmn4SduTUdISGO2/view) from displaymodule.com) (https://www.displaymodule.com/products/0-7-1920x1080-amoled-display-panel-lvds) connectors FF0881SA1-R3000 (https://www.mouser.com/ProductDetail/jae-electronics/ff0881sa1-r3000/?qs=e3doH35UsB4mcpzu8vQ7Tw%3D%3D)
- Custom LVDS to transfer the video data
- SPI for setup and configure

- IFSW probably can switch the LV inputs
- Open-Q µSOM 820: (https://www.lantronix.com/products/open-q-820-usom/) 50x25mm, HW spec (https://support.intrinsyc.com/documents/576)
- SoC: Snapdragon 820 (https://developer.qualcomm.com/qfile/35457/lm80-p2751-1_e.pdf)
- RAM: 3GB
- WiFi: AC
- Bluetooth: 4.1
- Flash: UFS 32GB
- 2 MIPI DSI 4L
- 3 MIPI CSI 4L
- Decode: 4K@60 H264, VP8/9, HEVC 8/10bit
- Encode: 4K@30 H264, VP8, HEVC
- Design is available for open hardware Dragonboard 820c (https://www.96boards.org/documentation/consumer/dragonboard/dragonboard820c/hardware-docs/)
- USB-C Left: PD for power/quick charging, Input DP alt-mode (4 lanes), USB2 OTG, ADB/Fastboot device
- LT7911D: (http://cn.lontiumsemi.com/UploadFiles/pdf/LT7911D_Product_Brief.pdf) converts DP to MIPI CSI/DSI, should be in sleep and not spend much power if USB-C Left is not connected. I2C/SPI interface to switch the modes (mono/stereo) and sleep/wake the chip.
- USB-C Right: PD for power/quick charging, powering the connected devices, switchable USB2/3 OTG or HDMI output
- Headset jack: TRRS 2.5
- Battery: 2x 1200mAh LiPo battery with JST 1.25 PH 2 Pin connector
- IMU: gyro/accel/mag for simple head motion control (not precise)
- Buttons: volume, power, home, back
- Low power LEDs: PWR - power, RUN - active, 2xCRG - battery charge indicator
- Touchpad: mouse control in the UI
- 2x1W audio speakers: mini bone-conduction speakers

# Goal parameters

- Weight of the product: <=80g (perfect value: 20g)
- Pressure on the nose: <=40g (perfect value: 15g)
- Input video display lag (HW from input to display pixel change): <= 14ms
- Product cost: <= $3000
- Autonomous work of the most power-consuming use case for >= 2 hours

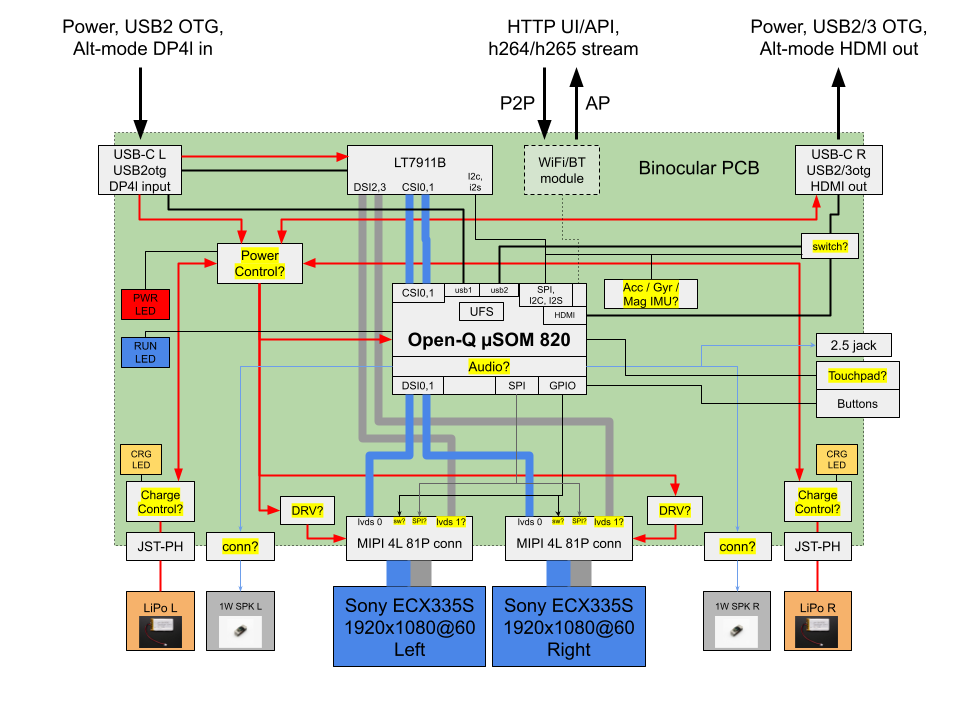
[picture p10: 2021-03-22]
design/prototype_1/Schema.png

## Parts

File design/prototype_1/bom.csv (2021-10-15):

Sequence | Description | Location | Pcs | Vendor Part Number | Vendor name | 6 setsneeded quantity | Unit price $
1 | TUSB564 USB Type-C 8.1-Gbps DP Alt Mode linear redriver crosspoint switch for sink side,WQFN (40),5x6mm,TI | U401 | 1 | TUSB564RNQR | TI | 6 | $19.14
2 | TPD6S300 USB Type-C™ Port Protector: Short-to-VBUS Overvoltage and IEC ESD Protection,WQFN (20),3X3mm, | U402,U504 | 2 | TPD6S300RUKR | TI | 12 | $8.92
3 | TS3USB30E ESD-Protected, High-Speed USB 2.0,1:2 Multiplexer/Demultiplexer Switch With Single Enable, UQFN (10),1.8X4mm,TI | U403,U404,U405,U502 | 4 | TS3USB30ERSWR | TI | 24 | $1.08
4 | TPD4S010DQAR 4-Lines,Uni-directional,0.05pF,TVS Arrays,DFN-10L ,2.5x1x0.58mm,TI | U406,U407,U505,U506 | 4 | TPD4S010DQAR | TI | 24 | $1.22
 | RClamp0524P.TCT 4-Lines,Uni-directional,0.3pF,TVS Arrays,10Pin,2.5x1x0.58mm,Semetch |  | 4 | RClamp0524P.TCT | Semetch | 24 | $2.24
 | WS05-4R2P 4-Lines,Uni-directional,0.3pF,TVS Arrays,DFN-10L ,2.5x1x0.58mm,Way-on |  | 4 | WS05-4R2P | Way-on | 24 | $0.32
 | ESDA6V8UD-10/TR 4-Lines,Uni-directional,0.4pF,TVS Arrays,DFN-10L ,2.5x1x0.58mm,Willsemi |  | 4 | ESDA6V8UD-10/TR | Willsemi | 24 | $0.27
5 | TUSB546-DCI USB Type-C DP ALT Mode linear redriver crosspoint switch,WQFN (40),4X6mm,TI | U501 | 1 | TUSB546-DCIRNQR | TI | 6 | $41.91
6 | TMUXHS4212 Two-Channel Differential 2:1 Mux / 1:2 Demux,VQFN (20),2.50mm × 4.50mm,TI | U503 | 1 | TMUXHS4212RKSR | TI | 6 | $1.04
7 | TC358775XBG,DSI to single/dual link LVDS to 1920x1200,BGA64,6x6mm,toshiba | U601,U602 | 2 | TC358775XBG | toshiba | 12 | $1.30
8 | LT3495B 650mA Micropower Low Noise Boost Converter,DFN-10,3X2mm,ADI | U603,U604 | 2 | LT3495BEDDB#TRPBF | ADI | 12 | $2.60
9 | SGM4563 4-Bit Level Translator For SPI Bus or UART Interface,UTQFN-1.8×1.8-12L,SGM | U701,U805 | 2 | SGM4563YUQN12G/TR | SGM | 12 | $0.65
10 | SGM4553 2-Bit Bidirectional Voltage-Level Translator,XTDFN-1.4×1-8L,SGM | U702,U804 | 2 | SGM4553YXDO8G/TR | SGM | 12 | $1.27
 | RS0102YUTDS8 2-Bit Bidirectional Voltage-Level Translator,DFN-1.4x1-8L,RUNIC |  | 2 | RS0102YUTDS8 | RUNIC | 12 | $1.35
11 | TXS0102DQE 2-Bit Bidirectional Voltage-Level Translator,X2SON(8),1.4x1mm,TI |  | 2 | TXS0102DQE | TI | 12 | $0.81
12 | BCT0102ETA-TR 2-Bit Bidirectional Voltage-Level Translator,XTDFN1.4x1-8L,Broadchip |  | 2 | BCT0102ETA-TR | Broadchip | 12 | $3.24
13 | SN74LVC1G08 Single 2-Input Positive-AND Gate,SON (6),1.45mm × 1.0mm,TI | U703,U704 | 2 | SN74LVC1G08DRYR | TI | 12 | $2.60
 | SGM7SZ08YUDL6G/TR Single 2-Input Positive-AND Gate,UTDFN-1.45x1-6L,SGM |  | 2 | SGM7SZ08YUDL6G/TR | SGM | 12 | $5.14
14 | LT7911D Type-C to Dual-port MIPI DSI/CSI with Audio,QFN64,7.5X7.5mm,Lontium | U705 | 1 | LT7911D | Lontium | 6 | $58.41
15 | SGM2578YG/TR Ultra Small, Low Input Voltage,Low RON Load Switch,WLCSP-0.9X0.9-4B,SGM | U708,U709,U710,U711 | 4 | SGM2578YG/TR | SGM | 24 | $22.17
 | CPS2140CS Ultra Small, Low Input Voltage,Low RON Load Switch,WLCSP-0.97X0.97-4B,Chiphome |  | 4 | CPS2140CS | Chiphome | 24 | $2.03
16 | TPS65988DJ Dual Port USB Type-C® and USB PD Controller,QFN (56),7mmX7mm,TI | U801 | 1 | TPS65988DJRSHR | TI | 6 | $0.97
17 | W25Q80DVUXIE 3V 8M-bit seral flash memory with dual and Quad SPI,WSON-8 3X2mm,Winbond | U802 | 1 | W25Q80DVUXIE | Winbond | 6 | $24.07
 | XT25F08BDFIGT-S 3V 8M-bit seral flash memory with dual and Quad SPI,WSON-8 3X2mm,XTX |  | 1 | XT25F08BDFIGT-S | XTX | 6 | $0.49
 | GD25WQ80EEIG 3V 8M-bit seral flash memory with dual and Quad SPI,WSON-8 3X2mm,GD |  | 1 | GD25WQ80EEIG | GD | 6 | $0.97
18 | ETA1090D3M,1MHz High Output current High Efficiency Synchronous Step-Up Converter, DFN3X3-12,ETA | U803 | 1 | ETA1090D3M | ETA | 6 | $0.03
19 | TLV1701AIDRLR,2.2-V to 36-V, microPower Comparator,SOT553 (5),1.20 mm × 1.60 mm,TI | U807,U808 | 2 | TLV1701AIDRLR | TI | 12 | $0.03
20 | BQ25616JRTWR 3.0-A Buck Battery Charger ,WQFN-24,4mmX4mm,TI | U901,U902 | 2 | BQ25616JRTWR | TI | 12 | $0.39
21 | LTC4412IS6#TRPBF Low Loss PowerPath™ Controller in ThinSOT,TSOT23-6,ADI | U903,U904 | 2 | LTC4412IS6#TRPBF | ADI | 12 | $0.11
22 | TLA2024IRUGR,4-Channel,12Bit ADC with I2C interface ,X2QFN, 10Pin,TI | U905 | 1 | TLA2024IRUGR | TI | 6 | $1.89
23 | WM8998ECS/R , High performance Audio Hub codec,W-CSP,Cirrus | U1001 | 1 | WM8998ECS/R | Cirrus | 6 | $0.03
24 | FDMA1024NZ Dual N-channel Mosfet,20V,5.0A,54mΩ,2x2mm,Onsemi | U1002 | 1 | FDMA1024NZ | Onsemi | 6 | $0.39
 | CJMND202 Dual N-channel Mosfet,20V,2.1A,45mΩ,2x2mm,JCET |  | 1 | CJMND202 | JCET | 6 | $0.04
25 | SN74AUP1G14DRY Low-Power Single Schmitt-Trigger Inverter,SON(6),1.45mmX1.0mm,TI | U1003 | 1 | SN74AUP1G14DRY | TI | 6 | $0.39
 | SGM7SZ04XUDL6G/TR Low-Power Single Schmitt-Trigger Inverter,UTDFN-1.45x1-6L,SGM |  |  | SGM7SZ04XUDL6G/TR | SGM | 6 | $0.03
26 | BNO08X family (BNO080/85/86) is a System in Package (SiP),28 pin LGA,Bosch | U1101 | 1 | BNO080/85/86 | Bosch | 6 | $0.49
27 | Crystal 27MHz 8pF ±10ppm 2520 | X701 | 1 | 27M |  | 6 | $0.32
28 | Crystal 32.768KHz 12.5pF ±20ppm 2012 | X1101 | 1 | 32.768K |  | 6 | $0.32
29 | CJBA3139K P-Channel mosfet,Vds:-20V,Vgs:±12V,Id:-0.66A,950mΩ,DFN1006-3L,JCET | Q301,Q809,Q810,Q811 | 4 | CJBA3139K | JCET | 24 | $0.20
 | PPM3FD20V1E P-Channel mosfet,Vds:-20V,Vgs:±10V,Id:-0.88A,860mΩ,DFN1006-3L,JCET |  | 4 | PPM3FD20V1E | Prisemi | 24 | $0.18
30 | SK3541 N-Channel mosfet,Vds:30V,Vgs:±20V,Id:100mA,SOT-723,Prisemi | Q803,Q804,Q805,Q812 | 4 | SK3541 | JCET | 24 | $0.08
 | PNM723T30V01 N-Channel mosfet,Vds:30V,Vgs:±20V,Id:100mA,SOT-723,JCET |  | 4 | PNM723T30V01 | Prisemi | 24 | $0.08
31 | CJMP3009G P-channel mosfet,Vds:-30V,Vgs:±20V,Id:-9A,12.5mΩ,2X2mm,JCET | Q801,Q802,Q806,Q807,Q903,Q904, Q905,Q906 | 8 | CJMP3009G | JCET | 48 | $0.03
 | FDMA530PZ P-channel mosfet,Vds:-30V,Vgs:±25V,Id:-6.8A,35mΩ,2X2mm,Onsemi |  | 8 | FDMA530PZ | Onsemi | 48 | $0.14
 | PPM6N30V9 P-channel mosfet,Vds:-30V,Vgs:±12V,Id:-9A,35mΩ,2X2mm,Prisemi |  | 8 | PPM6N30V9 | Prisemi | 48 | $0.14
32 | CJBA3134K N-Channel mosfet,Vds:20V,Vgs:±12V,Id:0.75A,900mΩ,DFN1006-3L,JCET | Q401,Q402,Q403,Q502,Q701,Q702, Q703,Q808 | 8 | CJBA3134K | JCET | 48 | $0.14
 | PNM3FD201E0 N-Channel mosfet,Vds:20V,Vgs:±8V,Id:0.3A,700mΩ,DFN1006-3L,Prisemi |  | 8 | PNM3FD201E0 | Prisemi | 48 | $2.27
33 | BZT52C5V1S Zener Diode,Vz:5.1V,200mW,SOD-323 | D605,D606 | 2 | BZT52C5V1S | JCET | 12 | $1.46
 | PZ3D5V1H Zener Diode,Vz:5.1V,200mW,SOD-323 |  | 2 | PZ3D5V1H | Prisemi | 12 | $4.87
34 | RB521S-40 schottky barrier diode,Vrwm:40V,Io:200mA,SOD-523,JCET | D603,D604 | 2 | RB521S-40 | SOD523 | 12 | $2.97
 | PSBD521S-40 schottky barrier diode,Vrwm:40V,Io:200mA,SOD-523,Prisemi |  | 2 | PSBD521S-40 | Prisemi | 12 | $0.10
35 | B5819WS schottky barrier diode,Vrwm:40V,Io:1A,SOD-323,JCET | D601,D602 | 2 | B5819WS | JCET | 12 | $1.75
 | PSBD3D40V1H schottky barrier diode,Vrwm:40V,Io:1A,SOD-323,Prisemi |  | 2 | PSBD3D40V1H | Prisemi | 12 | $1.12
36 | Inductor,WPN4012H6R8MT,Isat:1.6A,Irms:1.6A,DCR:0.226,4012,Sunlord | L601,L602 | 2 | WPN4012H6R8MT | Sunlord | 12 | $3.74
37 | Inductor,WPN4012H2R2MT,Isat:2.8A,Irms:2.7A,DCR:0.079,4012,Sunlord | L801 | 1 | WPN4012H2R2MT | Sunlord | 6 | $2.29
38 | Inductor,WPN252012E1R0MT,1uH,Isat:4.5A,Irms:3.5A,DCR:0.044,2520,Sunlord | L901,L902 | 2 | WPN252012E1R0MT | Sunlord | 12 | $0.10
 | Inductor,MPIA252012-1R0M-LF,1uH,Isat:3.8A,Irms:3.3A,DCR:0.057,2520,Microgate |  | 2 | MPIA252012-1R0M-LF | Microgate | 12 | $1.75
39 | TVS,JE05B1RD20-2 5V 1-Line Bi-directional Diode,0.5pF,100W,DFN1006-2,Jelan-Link | T409,T410 | 2 | JE05B1RD20-2 | Jelan-Link | 12 | $1.12
40 | TVS,JS05B1LD20-2 5V 1-Line Bi-directional Diode,110pF,200W,DFN1006-2,Jelan-Link | T901,T902 | 2 | JS05B1LD20-2 | Jelan-Link | 12 | $3.74
41 | TVS,JE12B1LD20-2A 12V 1-Line Bi-directional Diode,35pF,375W,DFN1006-2,Jelan-Link | T1001,T1002,T1003,T1004 | 4 | JE12B1LD20-2A | Jelan-Link | 24 | $2.29
42 | TVS,JE33B1RD20-2 3.3V 1-Line Bi-directional Diode,0.25pF,100W,DFN1006-2,Jelan-Link | T1101,T1102,T1103,T1104,T1105, T1106,T1107,T1108,T1109,T1110 | 10 | JE33B1RD20-2 | Jelan-Link | 60 | $0.08
43 | DF40C-100DS-0.4V(51),board to board connector,100Pin,0.2pitch,22.6X3.78X1.5mm,HRS | J301,J302,J501 | 3 | DF40C-100DS-0.4V(51V) | HRS | 18 | $1.34
44 | TYPE-C-31-M-04,Type-C Female connector,9.85x9.87x2.56mm,HRO | J401,J502 | 2 | TYPE-C-31-M-04 | HRO | 12 | $0.86
45 | FF0881SA1-R3000 Bottom contact 0.2mm narrow pitch,FPC thickness 0.15mm,81Pin,JAE | J601,J602 | 2 | FF0881SA1-R3000 | JAE | 12 | $2.88
46 | BM02B(3)B-ADHSS-GAN-ETB,2Pin,Pitch:1.3mm,5.7x4.3x1.75mm,JST | J901,J902 | 2 | BM02B-ADHSS-GAN-ETB | JST | 12
47 | PJ-237-A ￠2.5 12x5x3.2mm,SMD,HRO | J1003 | 1 | PJ-237-A | HRO | 6
48 | ST-1187-3,Tact switch,5.2X5.2X3mm,SMD,sunrise | J1101,J1102,J1103,J1104,J1106 | 5 | ST-1187-3 | sunrise | 30
49 | FPC connector, FH34SRJ-6S-0.5SH(50),6Pin,Pitch:0.5,4.9x3.3x1mm,FPC:0.3Glod,HRS | J1105 | 1 | FH34SRJ-6S-0.5SH | HRS | 6 | $1.76

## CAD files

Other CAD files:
design/prototype_1/Model.blend

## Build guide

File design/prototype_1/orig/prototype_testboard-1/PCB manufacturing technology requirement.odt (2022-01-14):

ＰＣＢProcessing technology requirements specification

1.Basic process information

Layers | 8 | Plate type | FR4
Finished plate thickness | 1MM | Finished sheet thickness tolerance | ＋／－１０％
ＰＣＢAcceptance Criteria | National Military Standard | Finished Dimensional Tolerance | ＋／－０．１５ｍｍ
Surface treatment | BGA adopts OSP process | Warpage | 0.75%
Solder mask color | blue | Via Process | plug hole
Character color | white | Craft side

2. Stackup Information

Finished Thickness(mm):1.0±0.1
AccountThickness(mm):0.97
LAYER STACKING
TOP | | | 0.5oz +Plating
| PP(3313) | 3.91
GND02 | | | 0.5oz
| Core | 5.12
ART03 | | | 0.5oz
| PP(1080*2) | 5.47
GND04 | | | 0.5oz
| Core | 3.94
ART05 | | | 0.5oz
| PP(1080*2) | 5.47
ART06 | | | 0.5oz
| Core | 5.12
GND07 | | | 0.5oz
| PP(3313) | 3.91
BOTTOM | | | 0.5oz +Plating

SINGLE IMPEDANCE：
| layer | width(mil) | impedance(ohm) | ref layer
| L1/L8 | 6 | 50 | L2/7
| L3/L6 | 4.8 | 50 | L2/4;L5/7
DIFFERENTIAL IMPEDANCE:
| layer | width/space(mil) | impedance(ohm) | ref layer
| L1/L8 | 4.5/9 | 100 | L2/7
| L3/L6 | 4.5/9 | 100 | L2/4;L5/7
| L1/L8 | 5\9 | 90 | L2/7
| L3/L6 | 5\9 | 90 | L2/4;L5/7

The board factory can adjust the line width according to the actual stack to achieve the purpose of controlling the impedance

3. Screenshot of Impedance Control

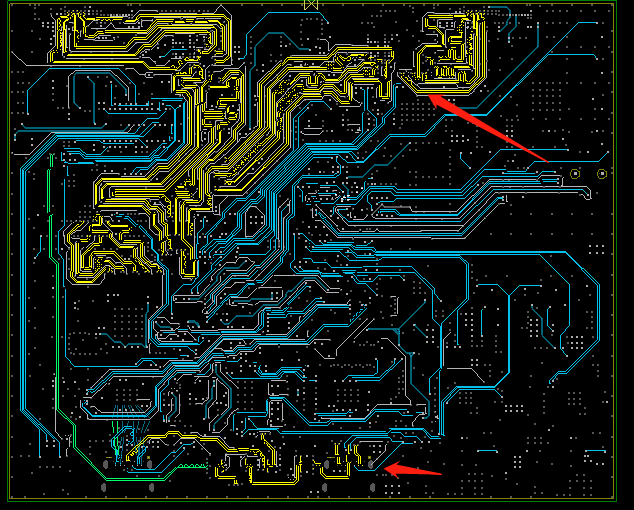
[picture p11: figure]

Yellow wire control 100ohm (L3)

Red line width control 90ohm (L3)

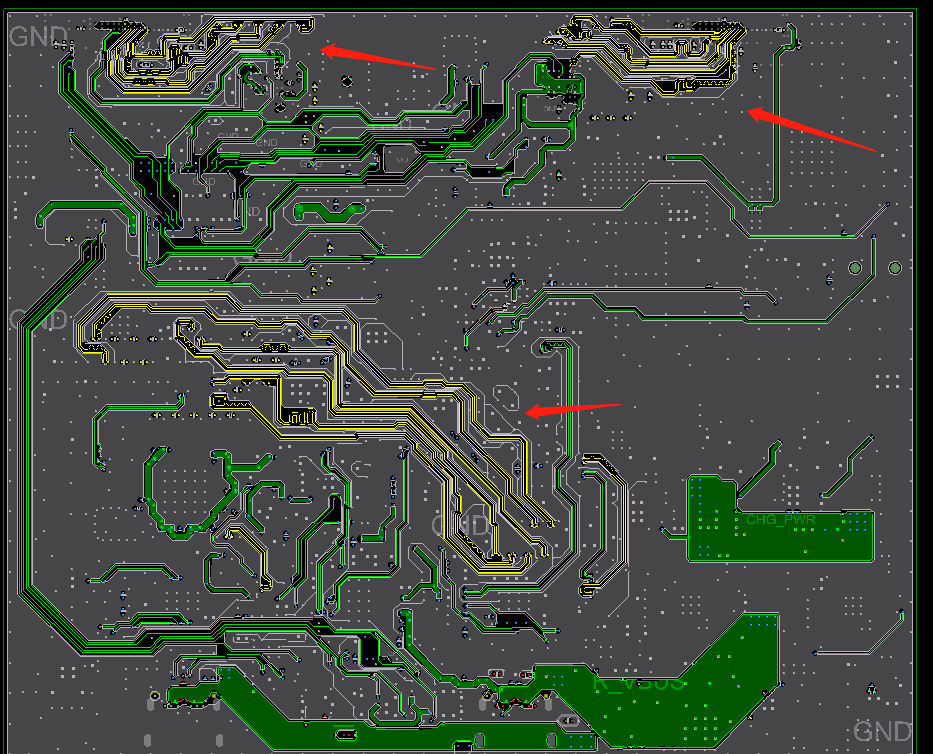
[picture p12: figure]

Yellow line width control 100ohm, (L6)

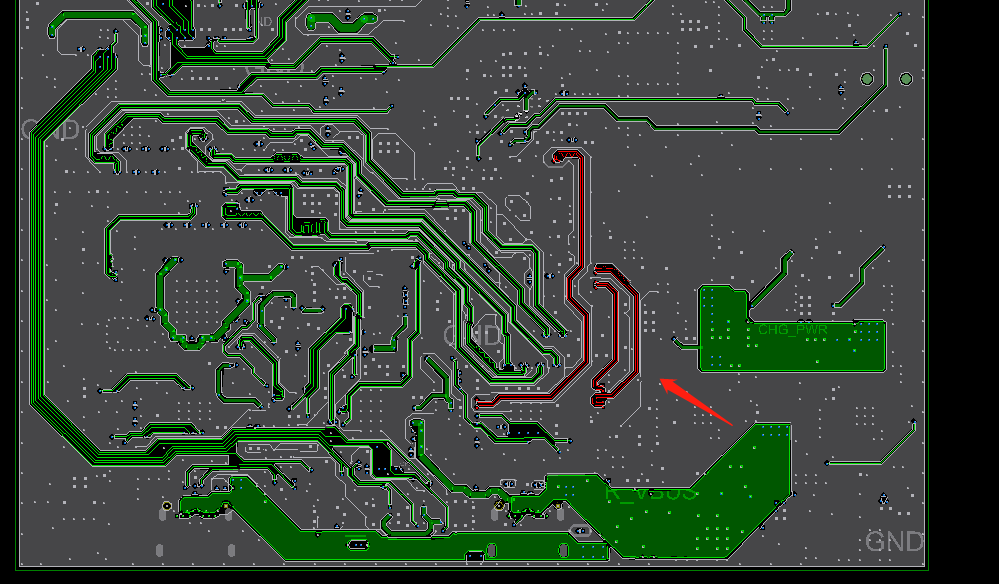
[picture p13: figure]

Red line width controlled 90ohm impedance (L6)

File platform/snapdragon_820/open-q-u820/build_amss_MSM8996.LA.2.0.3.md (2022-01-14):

# Build procedure for AMSS MSM8996.LA.2.0.3

## Requirements

* Docker
* ARM DS-5 and license (ARMCompiler 5.05u1) - https://developer.arm.com/tools-and-software/embedded/legacy-tools/ds-5-development-studio
* AMSS for MSM8996 LA.2.0.3 - qualcomm.com
* ~20GB to complete build

## Build

* Prepare the build directory 
   ```
   $ mkdir /srv/user/amss
   $ docker run --rm -it -v /srv/user/amss:/build:z ubuntu:18.04
   ```

* Unpack AMSS archive to `/srv/user/amss` directory - you will see a bunch of directories including
`rpm_proc`.

* ARM Compiler:
   * Unpack the DS-5 installer into `/srv/user/amss/tool`:
      ```
      $ cd /srv/user/amss
      $ mkdir tool ; cd tool
      $ unzip ~/Downloads/ARM\ DS\ 5\ Development\ Studio\ 5.20.2.zip
      ```
   * Run the DS-5 installer inside the docker container:
      ```
      root@34288fd1750d:/# cd /build
      root@34288fd1750d:/build# tool/install.sh --i-agree-to-the-contained-eula --no-interactive
      ```
   * Install the necessary libraries for the ARM compiler:
      ```
      root@34288fd1750d:/# dpkg --add-architecture i386 && apt update && apt install -y libasound2 libatk1.0-0 libcairo2 libgl1 libglu1-mesa libgtk2.0-0 libxt6 libxtst6 libwebkitgtk-1.0-0
      root@34288fd1750d:/# apt install -y libc6:i386 libfontconfig1:i386 libgl1:i386 libglu1-mesa:i386 libice6:i386 libncurses5:i386 libsm6:i386 libusb-0.1-4:i386 libxcursor1:i386 libxft2:i386 libxmu6:i386 libxrandr2:i386
      ```
   * Check that all the required libs are installed - the command should show `Running dependency check
   [succeeded]`:
      ```
      root@34288fd1750d:/# /usr/local/DS-5/sw/dependency_check/dependency_check_linux-x86_64.sh
      ```
   * Copy your license to the docker container in `/usr/local/DS-5/license.dat`.
   * Remove the `/build/tool` directory in docker container.

* Install python 2.7 for scons and openssl for signing:
   ```
   root@34288fd1750d:/# apt install -y python2.7 openssl && update-alternatives --install /usr/bin/python python /usr/bin/python2.7 10
   ```

* Prepare the env file and source it to use variables:
   ```
   root@34288fd1750d:/# cd /build
   root@34288fd1750d:/build# cat <<\EOF > /build/env.sh
   export ARMTOOLS=RVCT41
   export ARMROOT=/usr/local/DS-5/sw/ARMCompiler5.05u1
   export ARMBIN=$ARMROOT/bin
   export ARMINC=$ARMROOT/include
   export ARMLIB=$ARMROOT/lib
   export ARMHOME=$ARMROOT ARMPATH=$ARMBIN ARMINCLUDE=$ARMINC ARM_COMPILER_PATH=$ARMBIN
   export PATH=$ARMBIN:$PATH

   export LM_LICENSE_FILE=/usr/local/DS-5/license.dat
   EOF
   root@34288fd1750d:/build# . ./env.sh
   ```

* Build RPM - /build/rpm_proc/build/ms/bin/AAAAANAAR/signed/rpm.mbn:
   ```
   root@34288fd1750d:/# cd /build
   root@34288fd1750d:/# sh rpm_proc/build/build_8996.sh
   ```

## Flash

TODO

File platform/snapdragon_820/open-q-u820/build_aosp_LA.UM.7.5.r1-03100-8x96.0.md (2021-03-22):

# Build procedure for LA.UM.7.5.r1-03100-8x96.0 Android 9 + Kernel 3.18

## Requirements

* Docker
* ~200GB for complete build

## Build

* Host:
   ```
   mkdir /srv/user/android
   docker run --rm -it -v /srv/user/android:/build:z ubuntu:18.04
   ```

* Download the required binaries: [gitlab](https://gitlab.com/rabits/bins/-/tree/master/binocular/prototype_1)
* Place them in `/srv/user/android/` directory
* Unpack patches.tar.gz in the `/srv/user/android` directory (it will create `patches` directory)

* Container prepare:
   ```
   apt update && apt install -y git vim build-essential flex bison libncurses-dev openssl libssl-dev dkms libelf-dev libudev-dev libpci-dev libiberty-dev autoconf bc repo wget python3 unzip zip rsync
   git config --global user.email "you@example.com"
   git config --global user.name "Your Name"
   ```

* Container download sources:
   ```
   mkdir -p /build/open-q-820
   cd /build/open-q-820
   repo init -u git://codeaurora.org/platform/manifest.git -b release -m LA.UM.7.5.r1-03100-8x96.0.xml --repo-url=git://codeaurora.org/tools/repo.git --repo-branch=caf-stable

   # Remove "google_" prefixed repos in .repo/manifest.xml

   cp .repo/repo/repo /usr/bin/repo
   repo sync -c -j$(nproc) --no-tags --no-clone-bundle
   ```

* Container apply vendor:
   ```
   # Apply patches from 8096_Open-Q_u820__Android_BSP-P_v5.1/8096_Open-Q_820_Android_BSP-P_v5.1/Source_Package/
   ../patch.sh

   # Extract proprietary.tar.gz from 8096_Open-Q_u820__Android_BSP-P_v5.1/8096_Open-Q_820_Android_BSP-P_v5.1/Source_Package/ to vendor/qcom/
   tar -xzvf ../8096_Open-Q_u820__Android_BSP-P_v5.1/proprietary.tar.gz -C vendor/qcom/
   ```

* Container build images:
   ```
   source build/envsetup.sh
   lunch msm8996-userdebug

   # Run build images
   BUILD_NUMBER=$(date +%y%m%d%H%M%S) ITC_ID=OpenQ820_P_v5.1 make -j24
   ```

## Flash

* Host prepare:
   ```
   $ adb reboot bootloader
   ```
   ```
   $ fastboot devices -l
   277010101071910397     fastboot
    usb:3-1.1.1.1.3
   ```

* Flash partitions:
   ```
   $ fastboot flash boot /srv/user/android/open-q-820/out/target/product/msm8996/boot.img
   Sending 'boot' (55589 KB)                          OKAY [  1.574s]
   Writing 'boot'                                     OKAY [  0.552s]
   Finished. Total time: 2.256s
   ```
   ```
   $ fastboot flash cache /srv/user/android/open-q-820/out/target/product/msm8996/cache.img
   Sending 'cache' (128 KB)                           OKAY [  0.047s]
   Writing 'cache'                                    OKAY [  0.029s]
   Finished. Total time: 0.128s
   ```
   ```
   $ fastboot flash persist /srv/user/android/open-q-820/out/target/product/msm8996/persist.img
   Sending 'persist' (32768 KB)                       OKAY [  1.018s]
   Writing 'persist'                                  OKAY [  0.336s]
   Finished. Total time: 1.404s
   ```
   ```
   $ flash system /srv/user/android/open-q-820/out/target/product/msm8996/system.img
   Sending sparse 'system' 1/3 (524284 KB)            OKAY [ 15.258s]
   Writing 'system'                                   OKAY [  5.027s]
   Sending sparse 'system' 2/3 (524284 KB)            OKAY [ 15.208s]
   Writing 'system'                                   OKAY [  5.033s]
   Sending sparse 'system' 3/3 (300564 KB)            OKAY [  8.694s]
   Writing 'system'                                   OKAY [  2.901s]
   Finished. Total time: 52.167s
   ```
   ```
   $ fastboot flash userdata /srv/user/android/open-q-820/out/target/product/msm8996/userdata.img
   Sending 'userdata' (5368 KB)                       OKAY [  0.197s]
   Writing 'userdata'                                 OKAY [  0.082s]
   Finished. Total time: 0.329s
   ```
   ```
   $ fastboot flash vendor /srv/user/android/open-q-820/out/target/product/msm8996/vendor.img
   Sending 'vendor' (406652 KB)                       OKAY [ 11.753s]
   Writing 'vendor'                                   OKAY [  3.903s]
   Finished. Total time: 15.701s
   ```
   ```
   $ fastboot flash recovery /srv/user/android/open-q-820/out/target/product/msm8996/recovery.img
   Sending 'recovery' (63009 KB)                      OKAY [  1.830s]
   Writing 'recovery'                                 OKAY [  0.624s]
   Finished. Total time: 2.503s
   ```

* Complete flashing and boot (could require secondary reboot):
   ```
   $ fastboot continue
   ```

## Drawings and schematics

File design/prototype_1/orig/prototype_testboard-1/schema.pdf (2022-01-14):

I2C

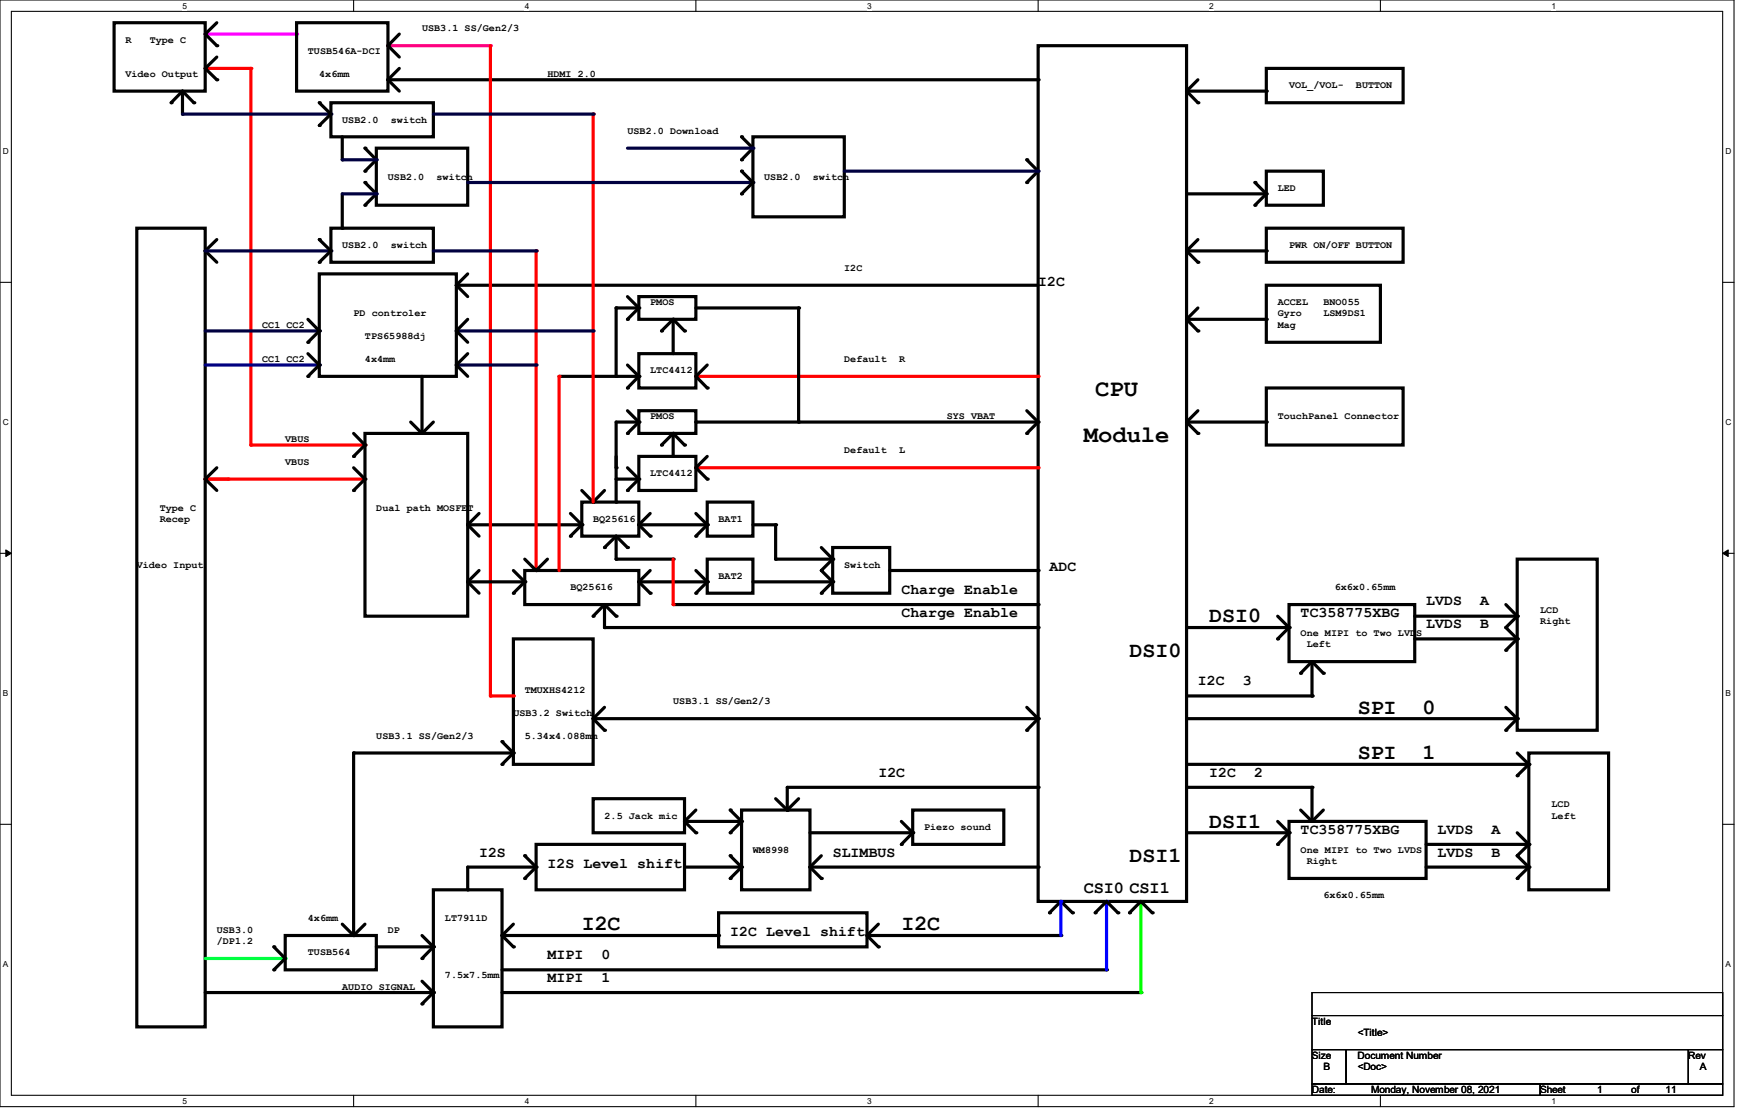
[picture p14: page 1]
A Title Size; Document Number; Rev Date:; Sheet; of <Doc>; <Title> B; Monday, November 08, 2021; 11 Title Size; R Type C; Type C Recep; TUSB546A-DCI; USB2.0 switch; TPS65988dj; PD controler; VBUS; HDMI 2.0; TUSB564; AUDIO SIGNAL; Video Output; Video Input; CPU; Module; USB3.0 /DP1.2; CSI0 CSI1; DSI0; DSI1; TMUXHS4212; USB3.1 SS/Gen2/3; BAT1; BAT2; LTC4412; PMOS; SYS_VBAT; SLIMBUS; Piezo sound; Switch; ADC; Charge Enable Charge Enable; Default L; Default R; 2.5 Jack mic; USB3.2 Switch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

PWR ON/OFF BUTTON

Dual path MOSFET

One MIPI to Two LVDS
Left

Right

J302

J501

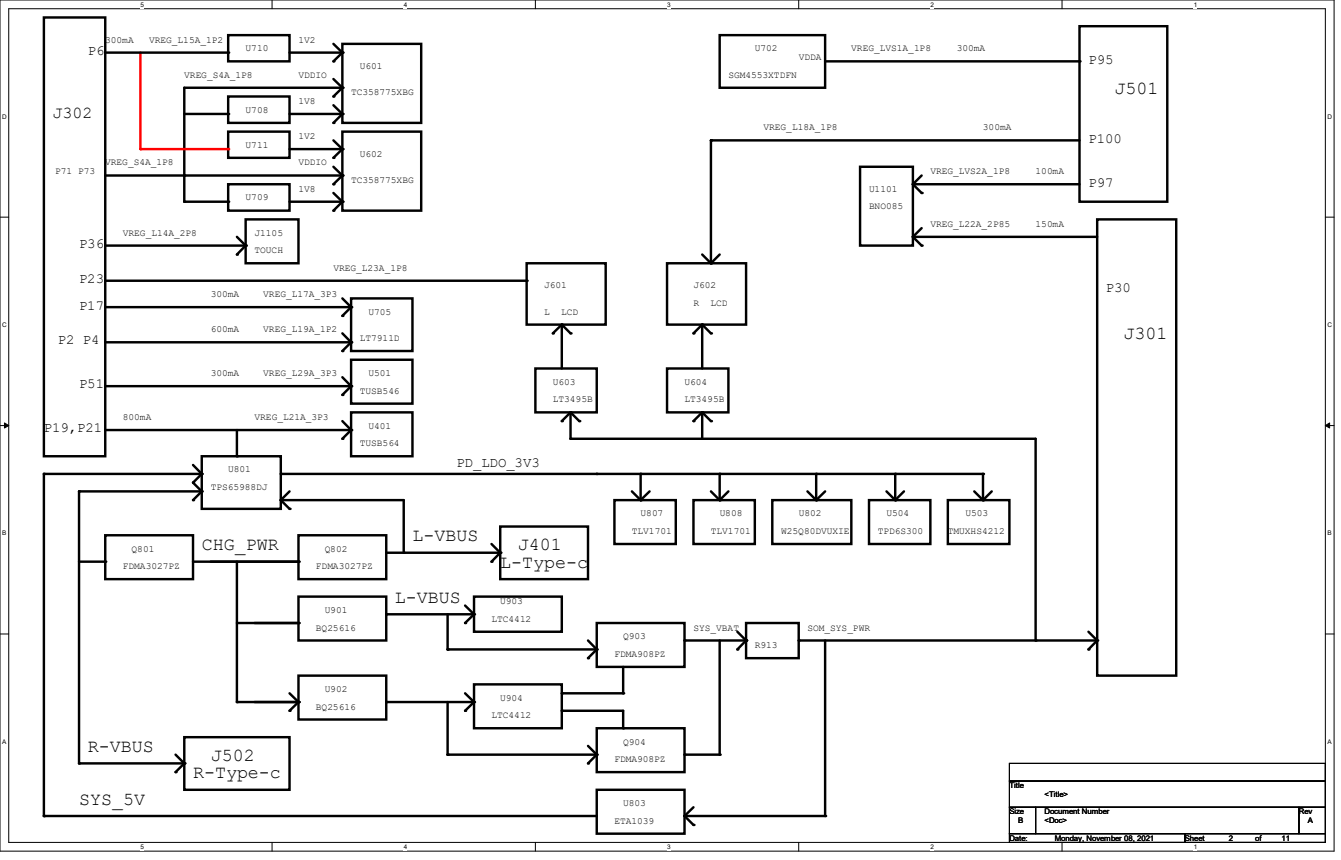
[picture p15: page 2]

# VREG_L17A_3P3 VREG_L21A_3P3 VREG_L23A_1P8 VREG_L29A_3P3 VREG_S4A_1P8

L_CHG_CE 9 SLIMBUS_DATA0 10 SLIMBUS_CLK 10 SSC_WAKE_PS0 11 SSC_SPI_1_CLK 11 SSC_SPI_1_CS_N 11 SSC_SPI_1_MOSI 11 SSC_SPI_1_MISO 11 SSC_NRST 11 R_FAULT 5

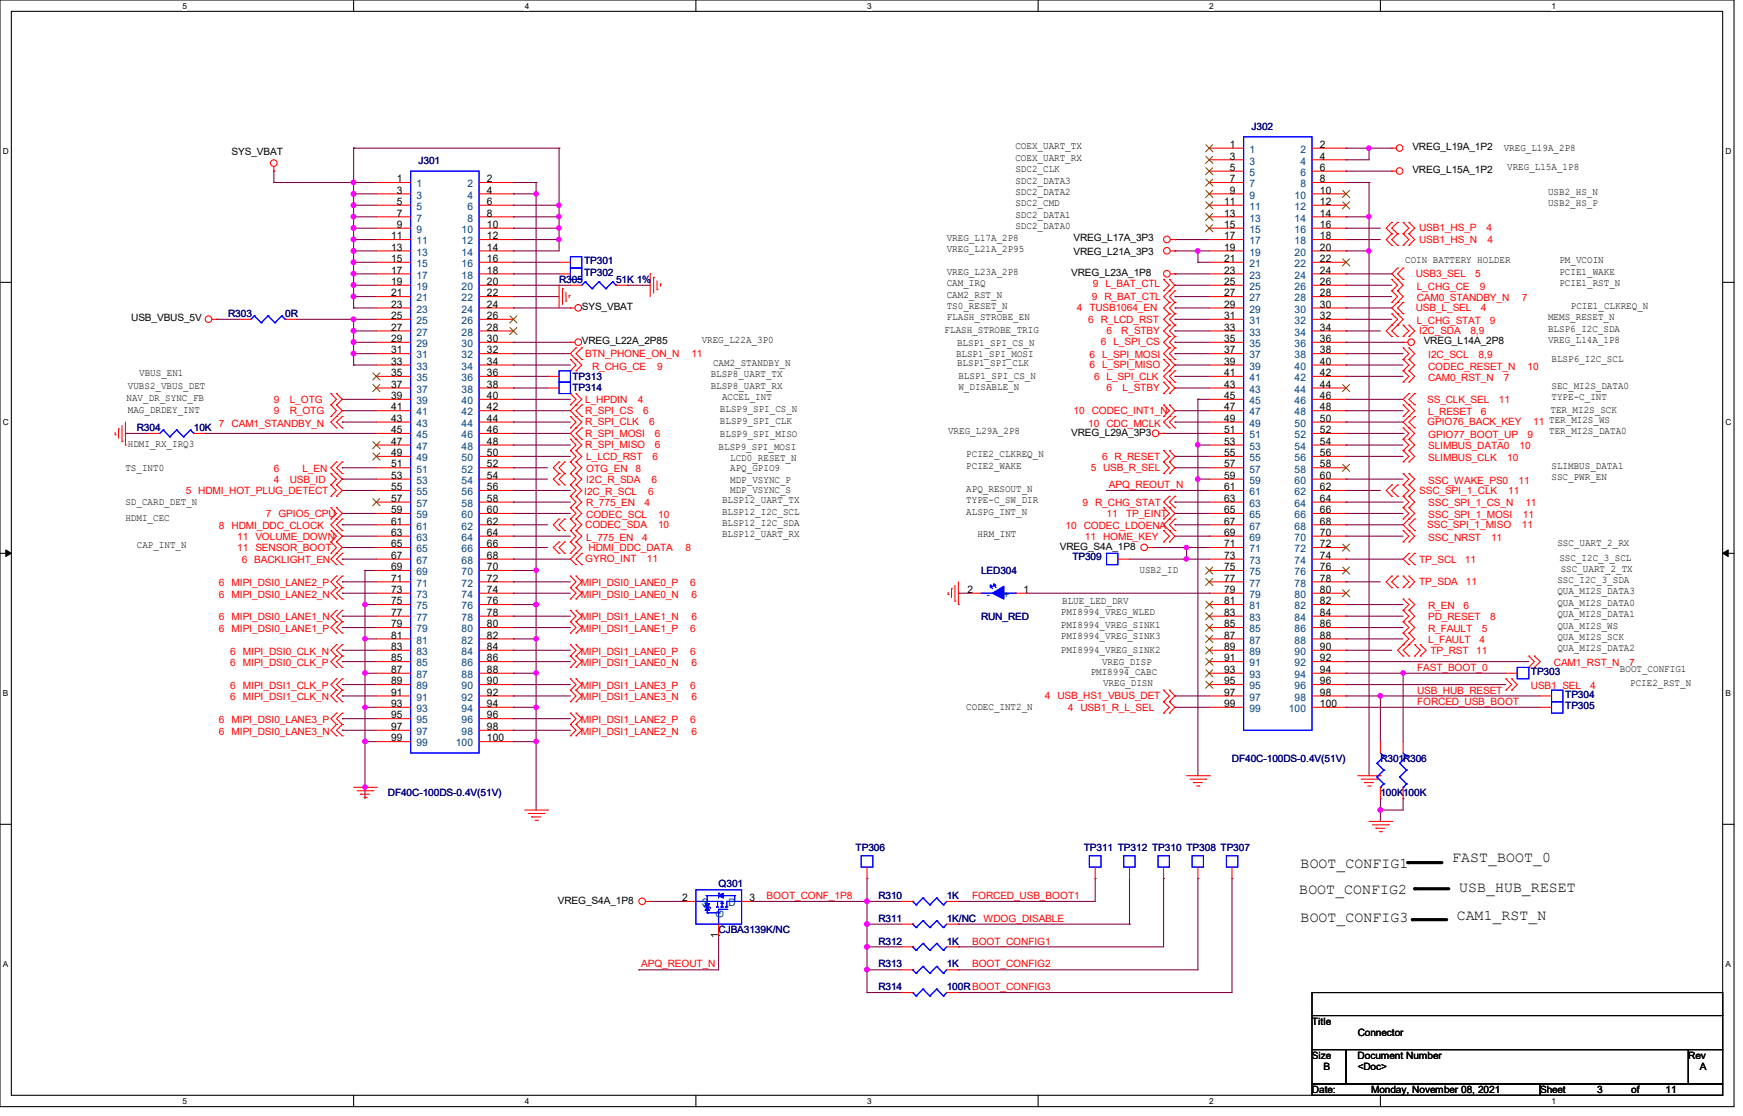
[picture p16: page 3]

# L_C_CC1 PB_L_D+ PB_L_D-

# L_RX1- L_RX2- L_TX2+

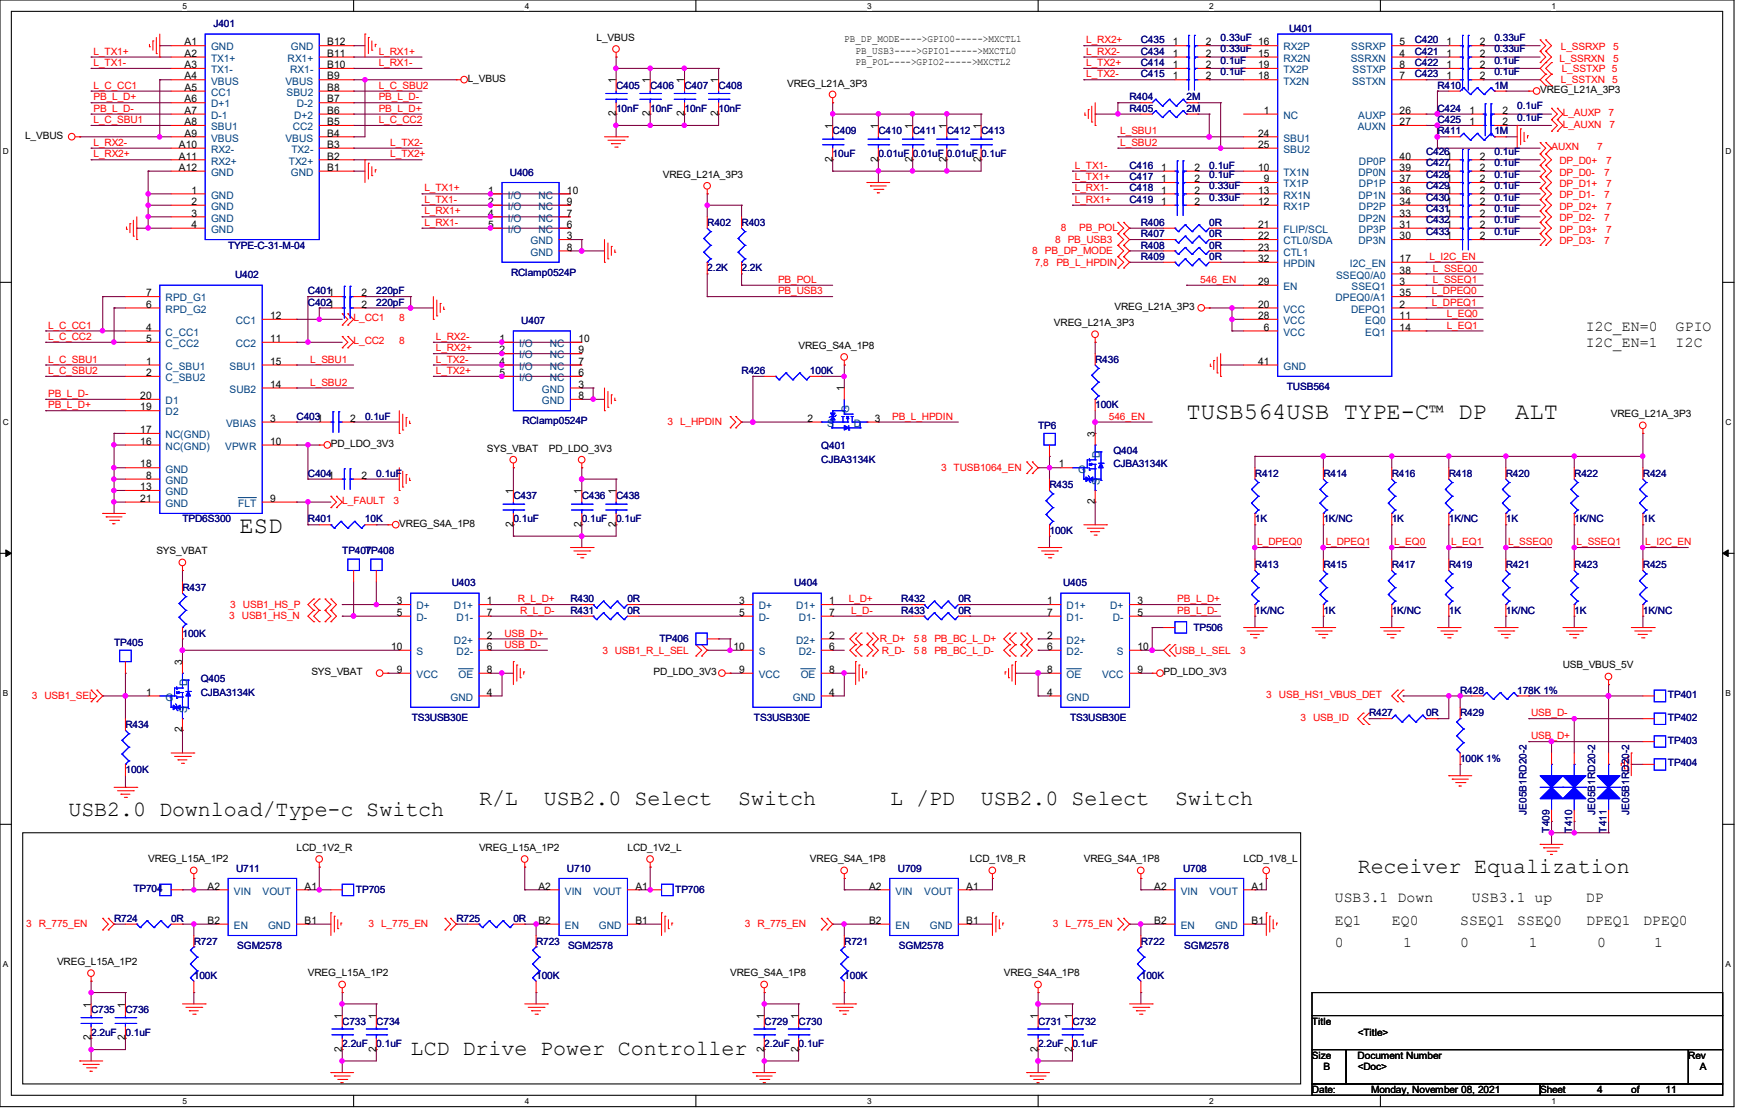
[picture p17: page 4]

# HDMI_TX2_P USB1_SS_TX_P USB1_SS_TX_N

SSRXP 5 | SSRXN 4 | SSTXP 8 | SSTXN 7 | AUXP 24 | AUXN 25 | DP0P 9 | DP0N 10 | DP1P 12 | DP1N 13 | DP2P 15 | DP2N 16 | DP3P 18 | DP3N 19

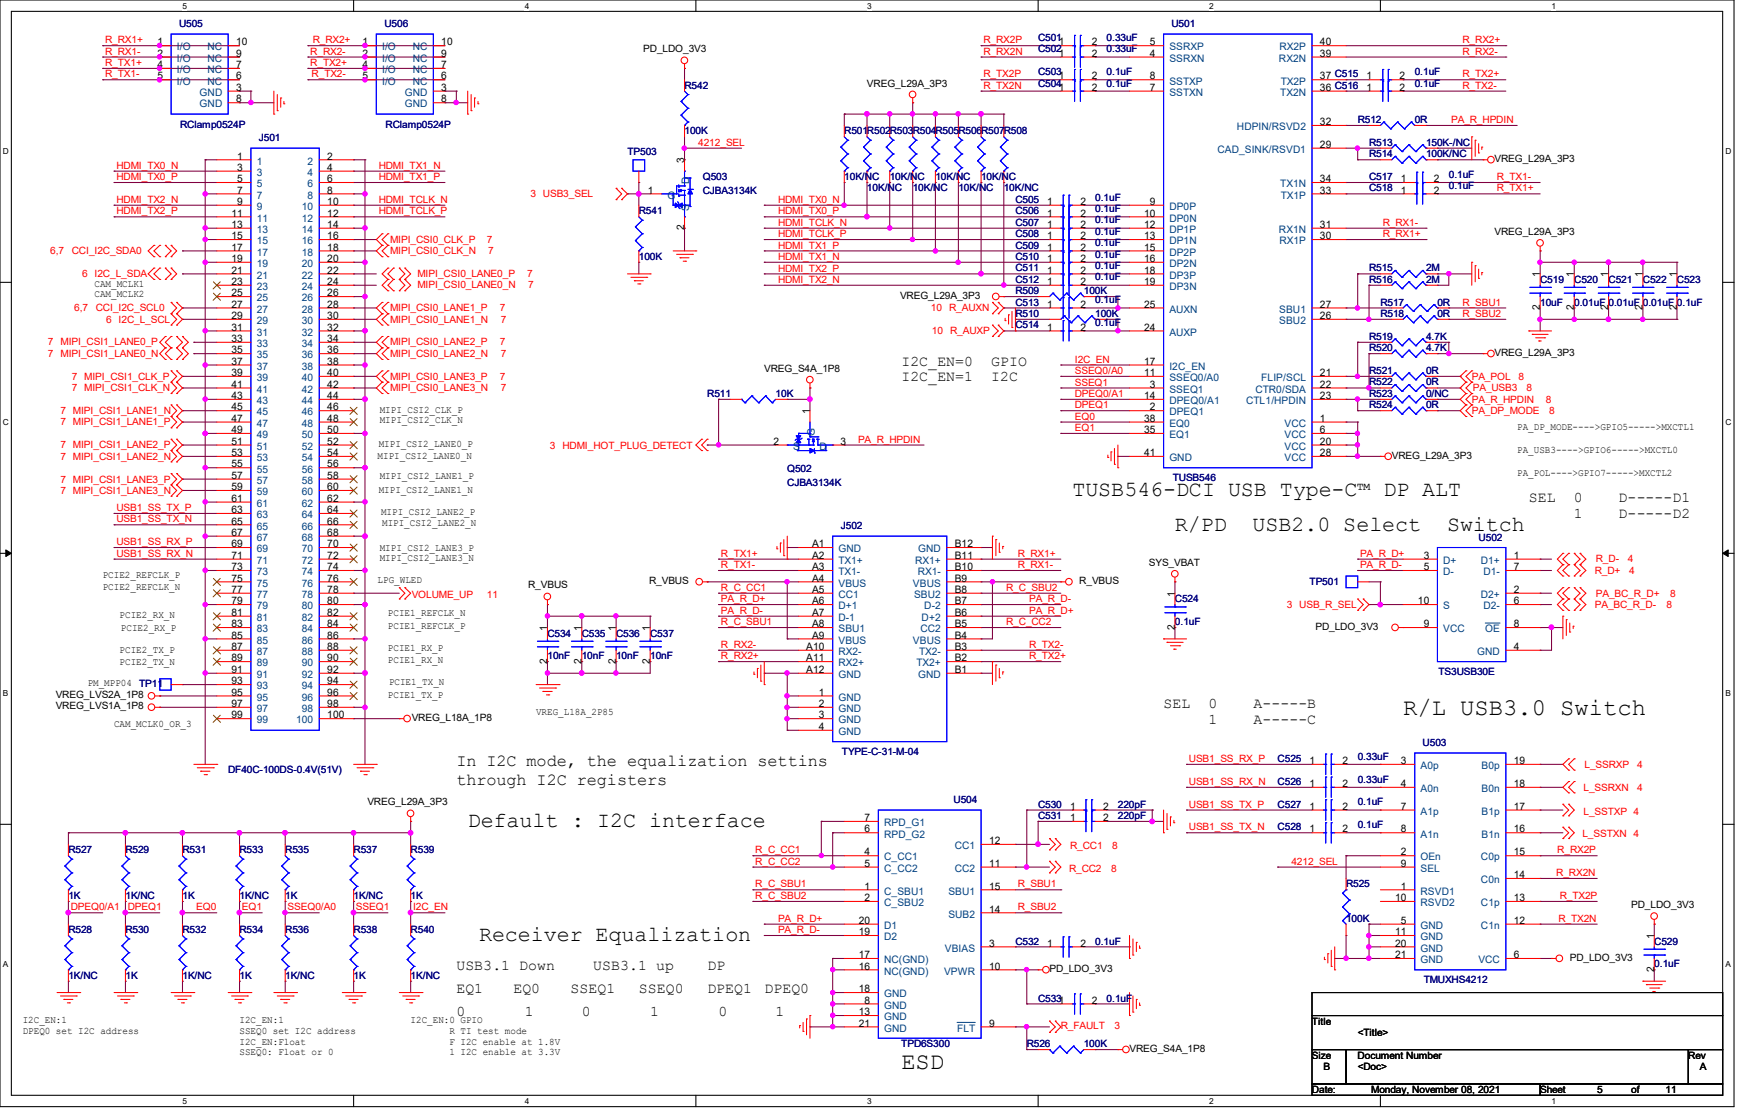
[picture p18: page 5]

TUSB546-DCI USB Type-C™ DP ALT

In I2C mode, the equalization settins
through I2C registers
Default : I2C interface

# RLV5A RLV5B RLV2A RLV2B RLV3A RLV3B RLV9A RLV9B RLV6A RLV6B RLV7A RLV7B

# L_VDD_10V R_VDD_10V

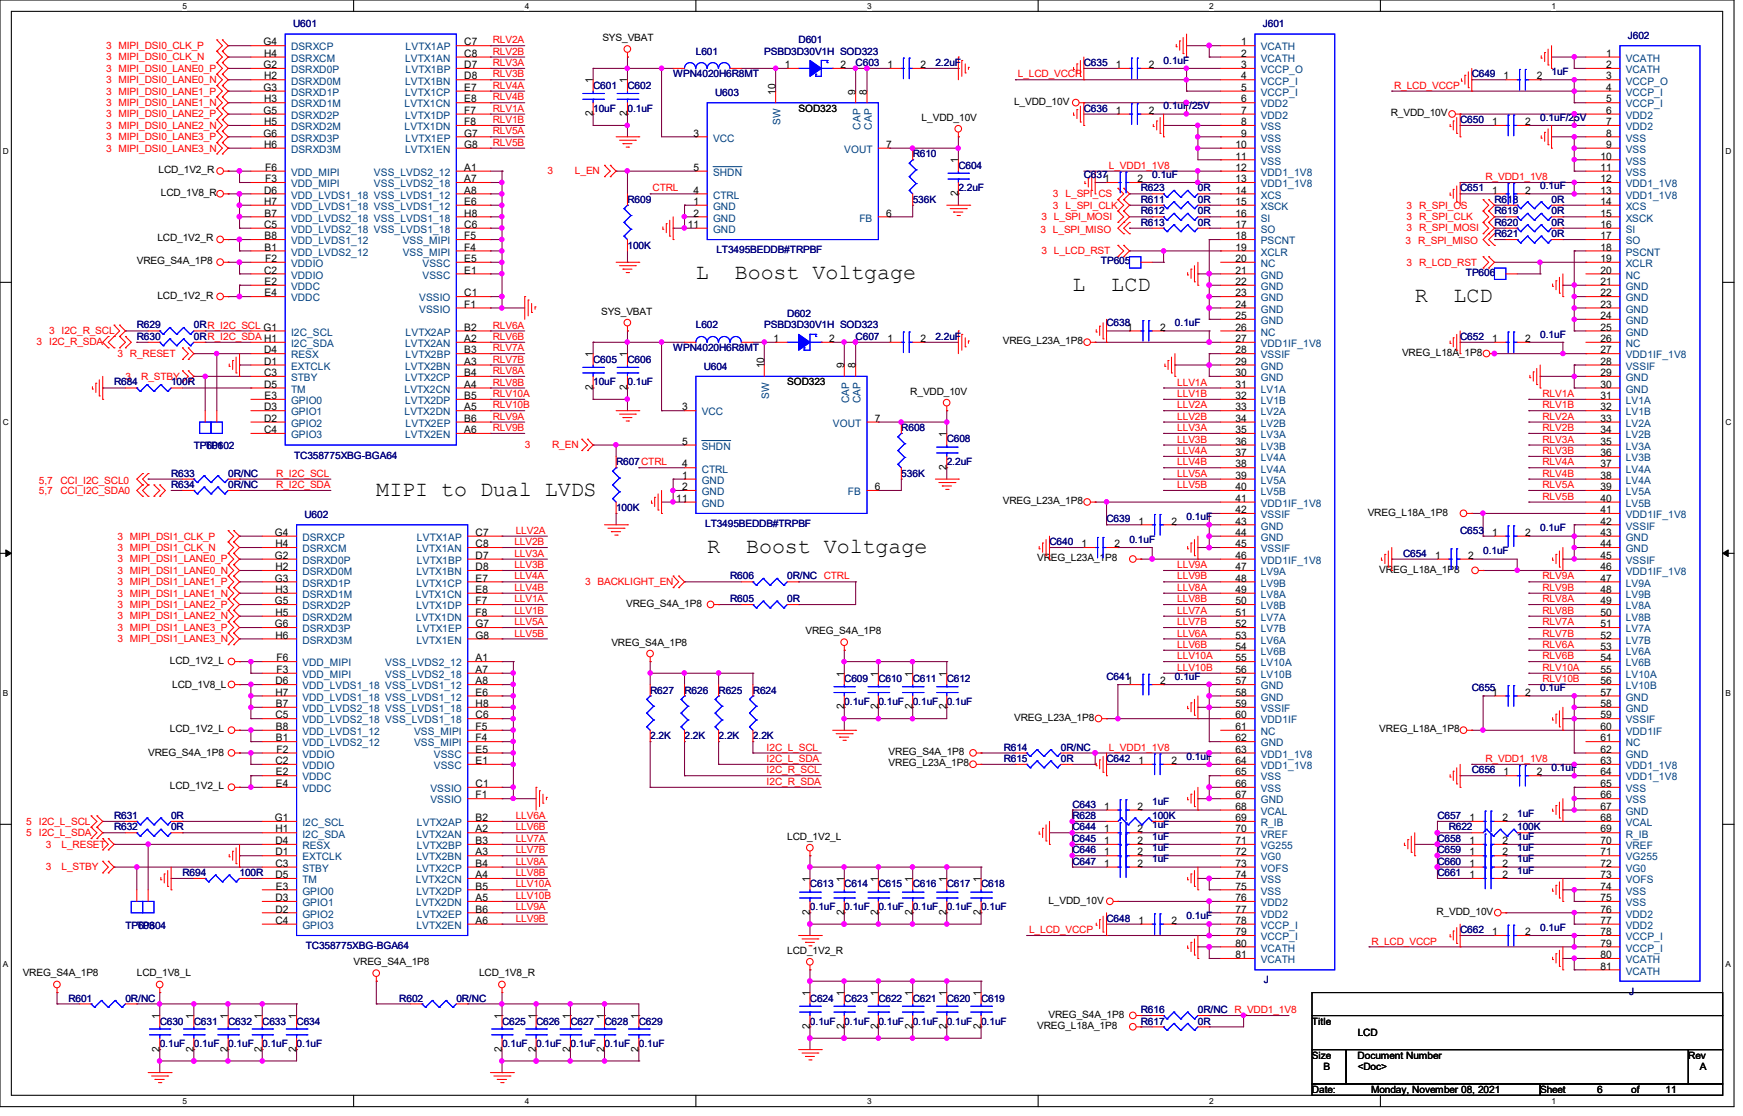
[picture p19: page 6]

9 VCC 3 SHDN 5 CTRL 4 GND 1 FB 6 VOUT 7 GND 2 GND 11 CAP

MIPI to Dual LVDS

# I2S Level Shift

1.8*1.8

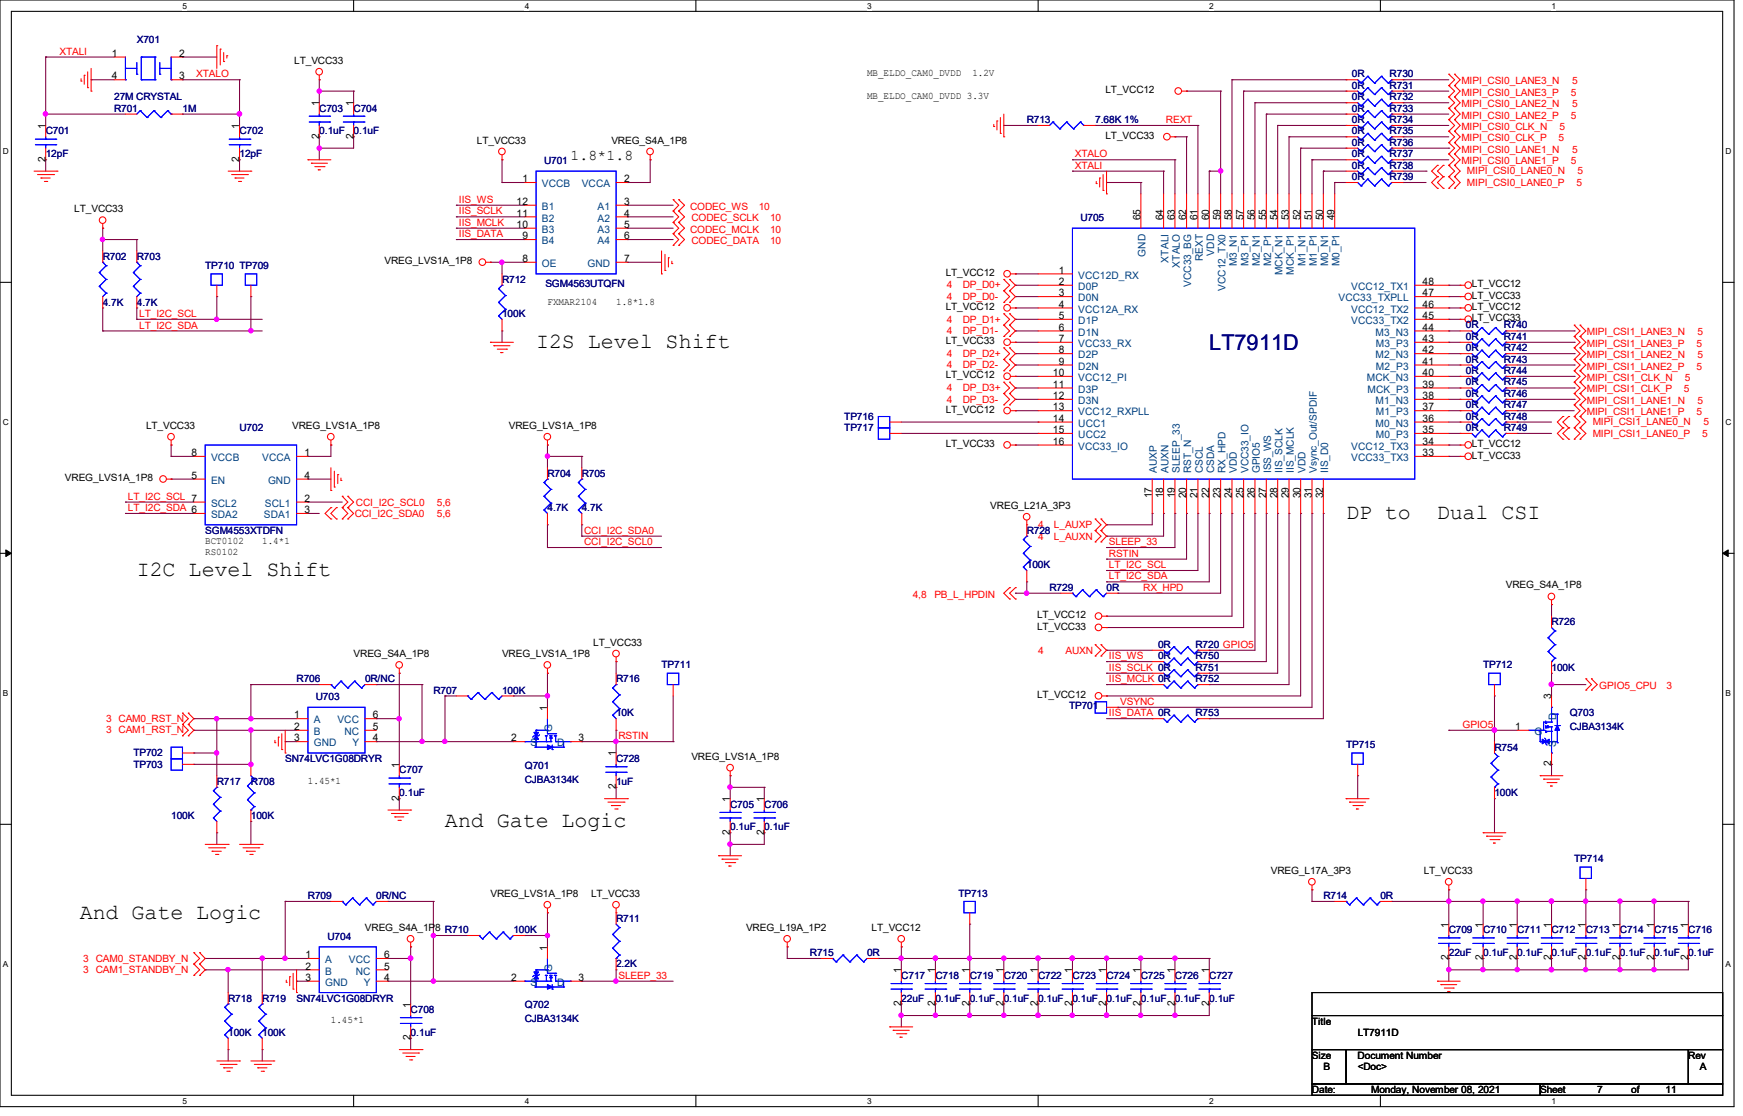
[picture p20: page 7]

DP to Dual CSI

0 | 0 | 5V
0 | 1 | 9V

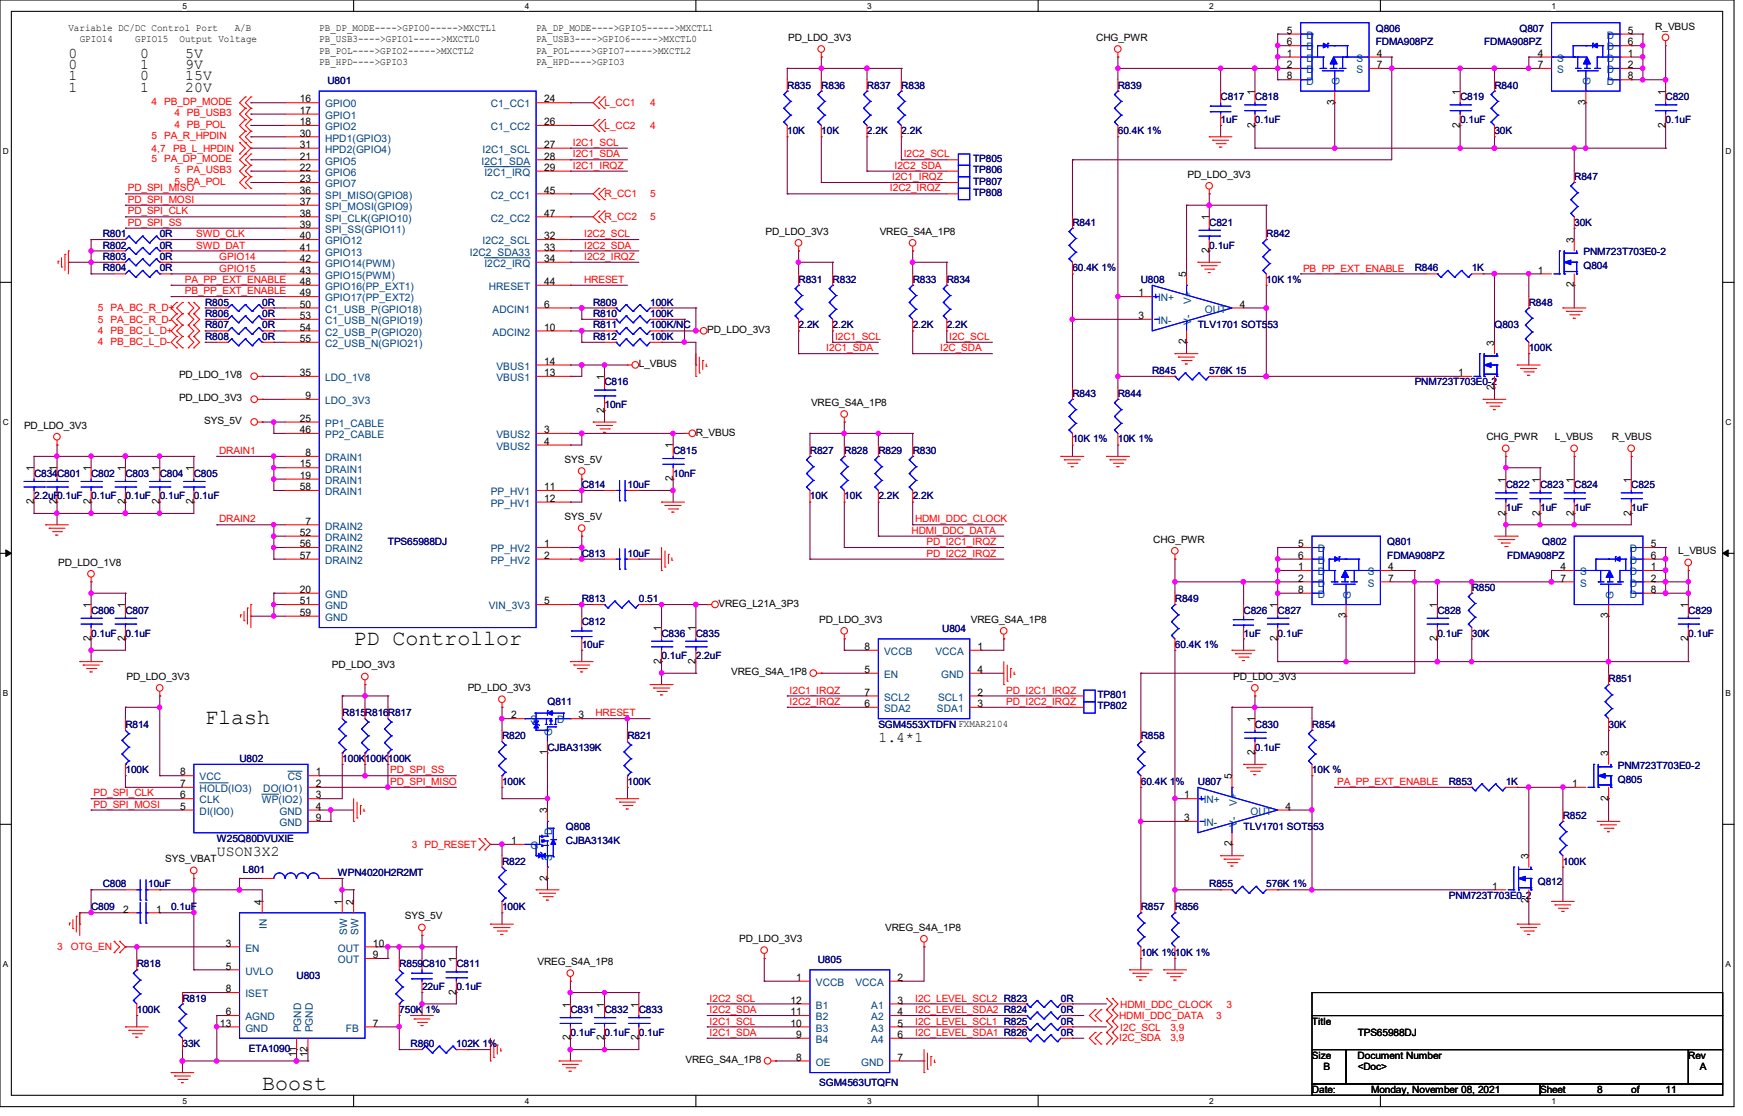
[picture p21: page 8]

## PPM6N20V10

# Vbus Less than 13.5V, max 3.2A TP908 C928

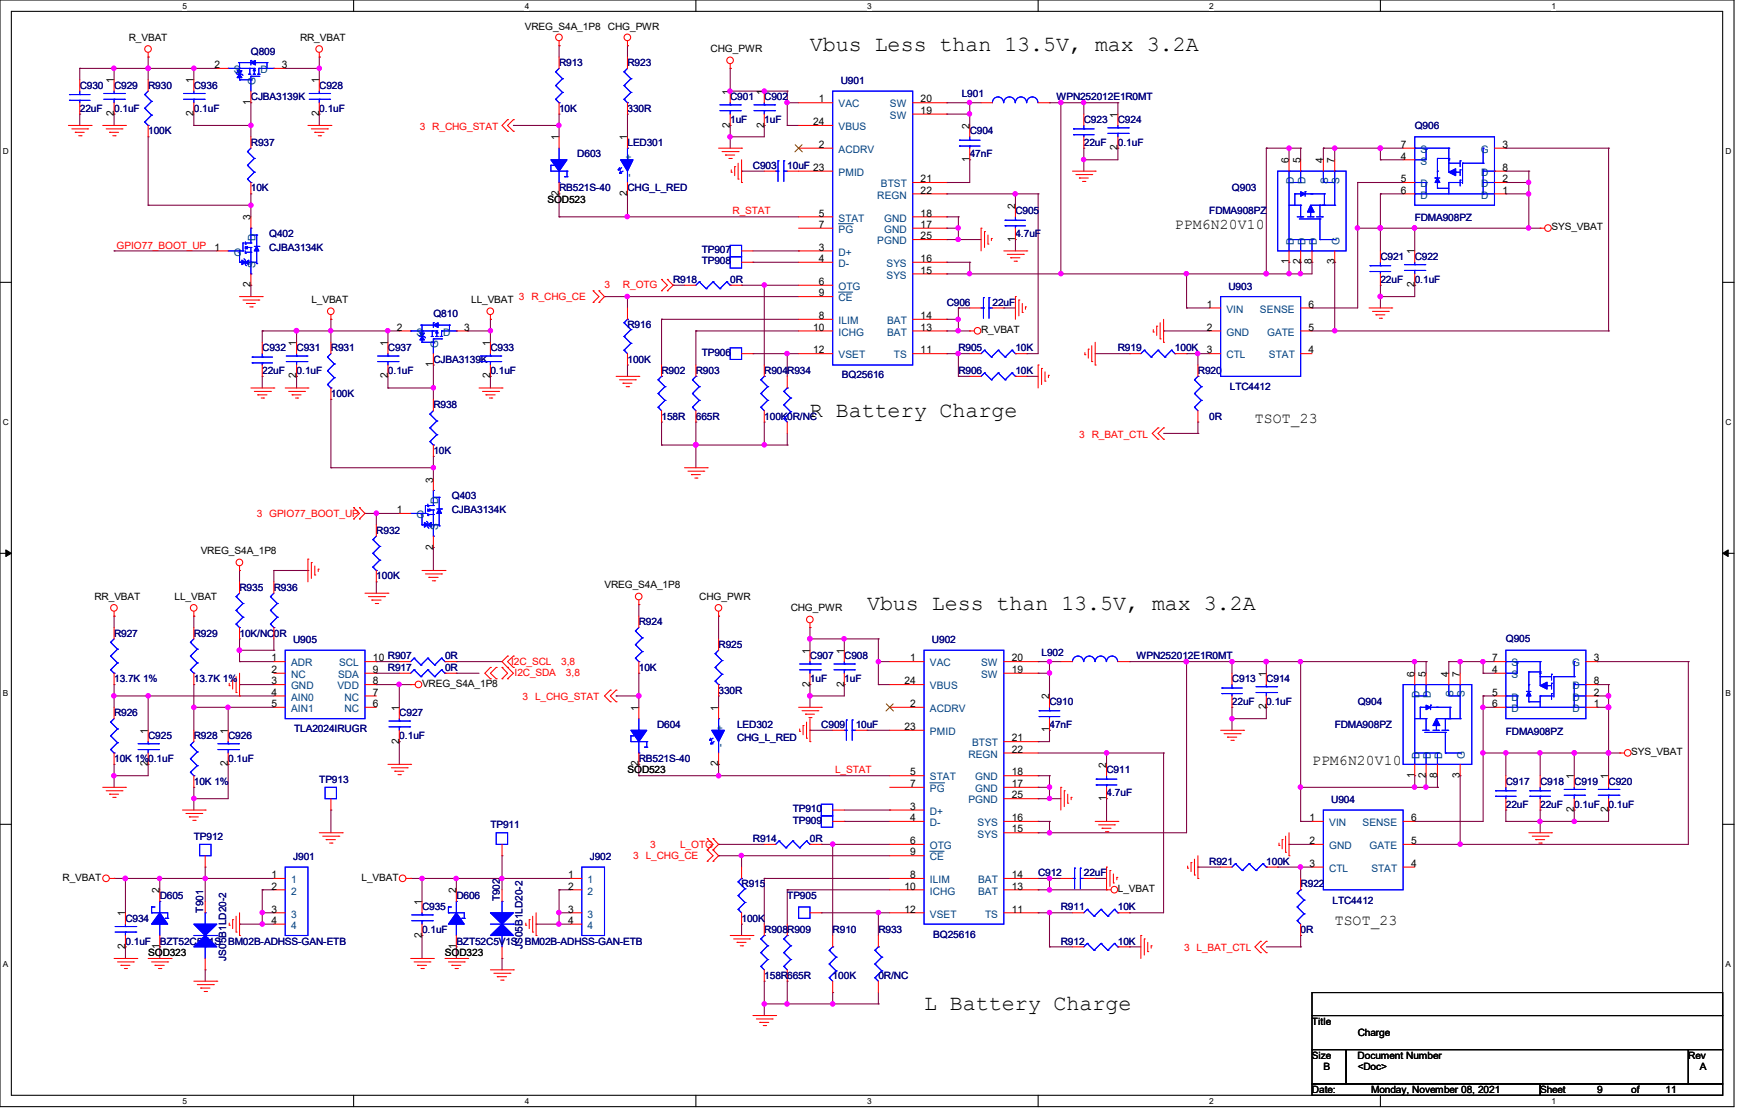
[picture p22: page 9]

Vbus Less than 13.5V, max 3.2A

# DCVDD 1.2V DCVDD 1.8V

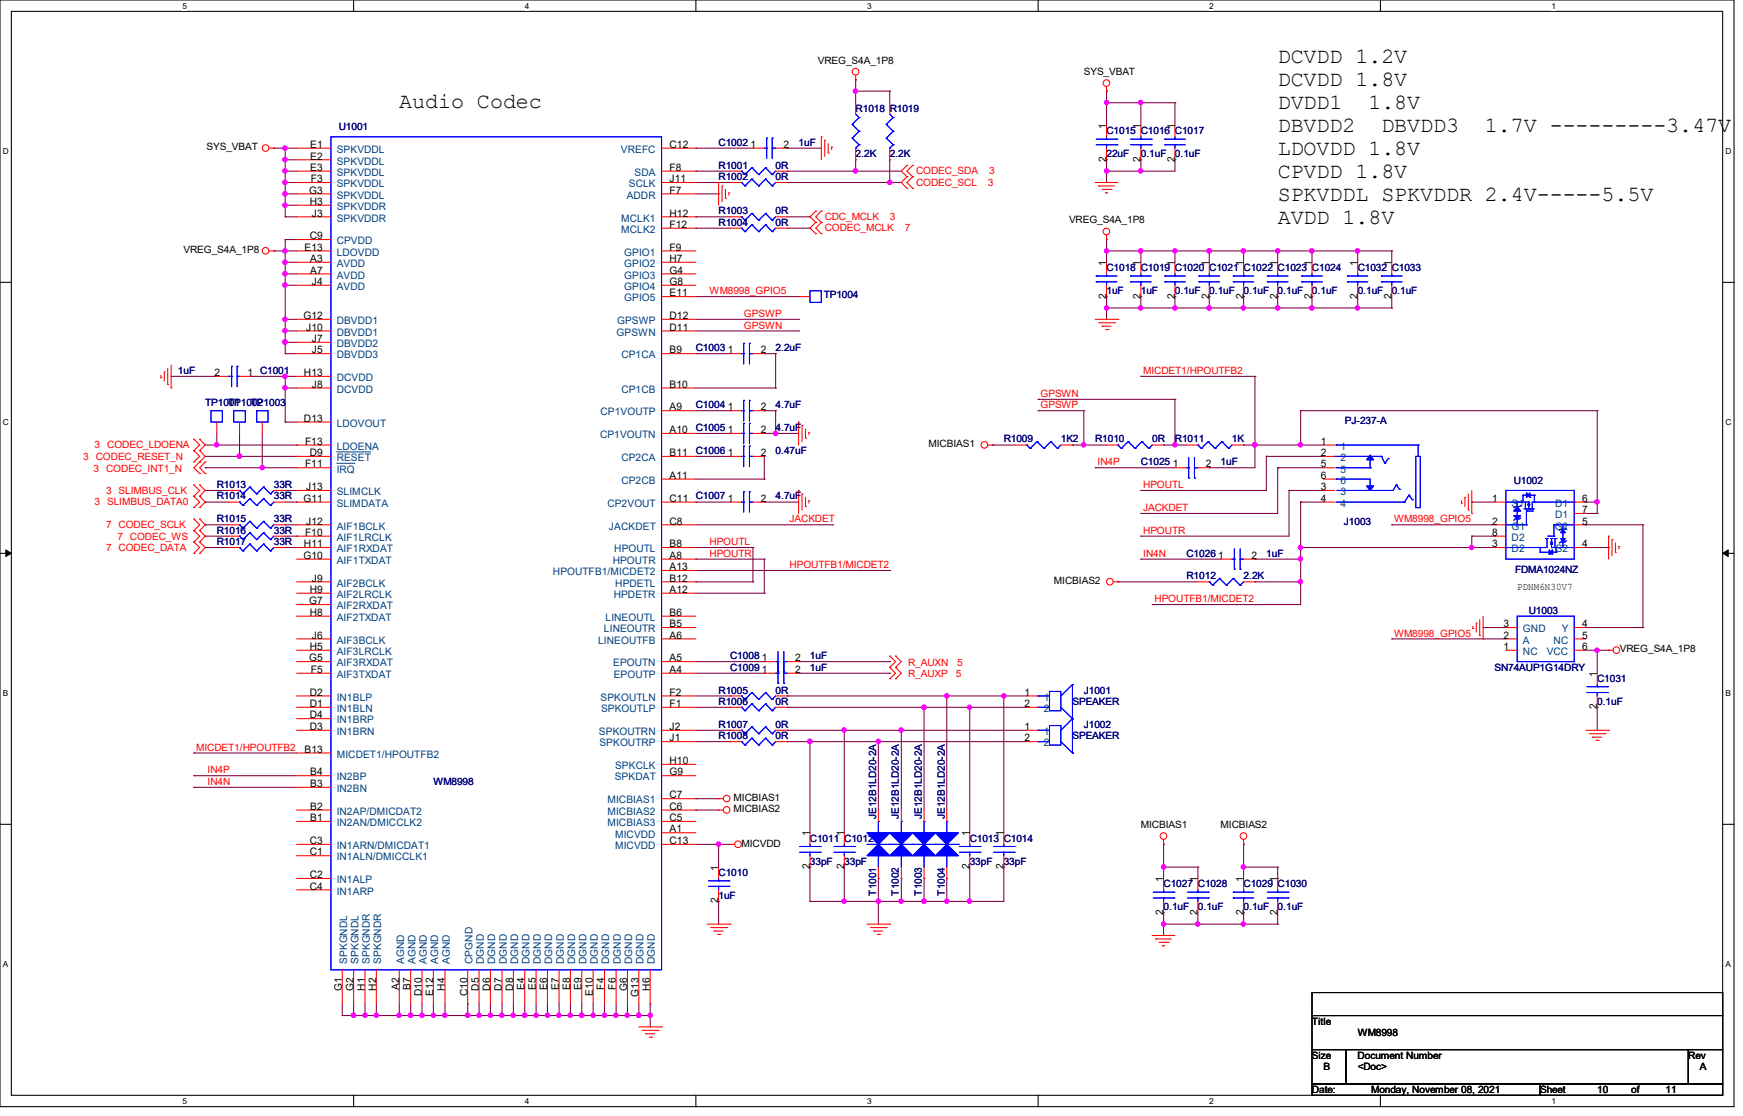
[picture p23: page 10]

GPSWP GPSWN

D D

## VREG_L22A_2P85

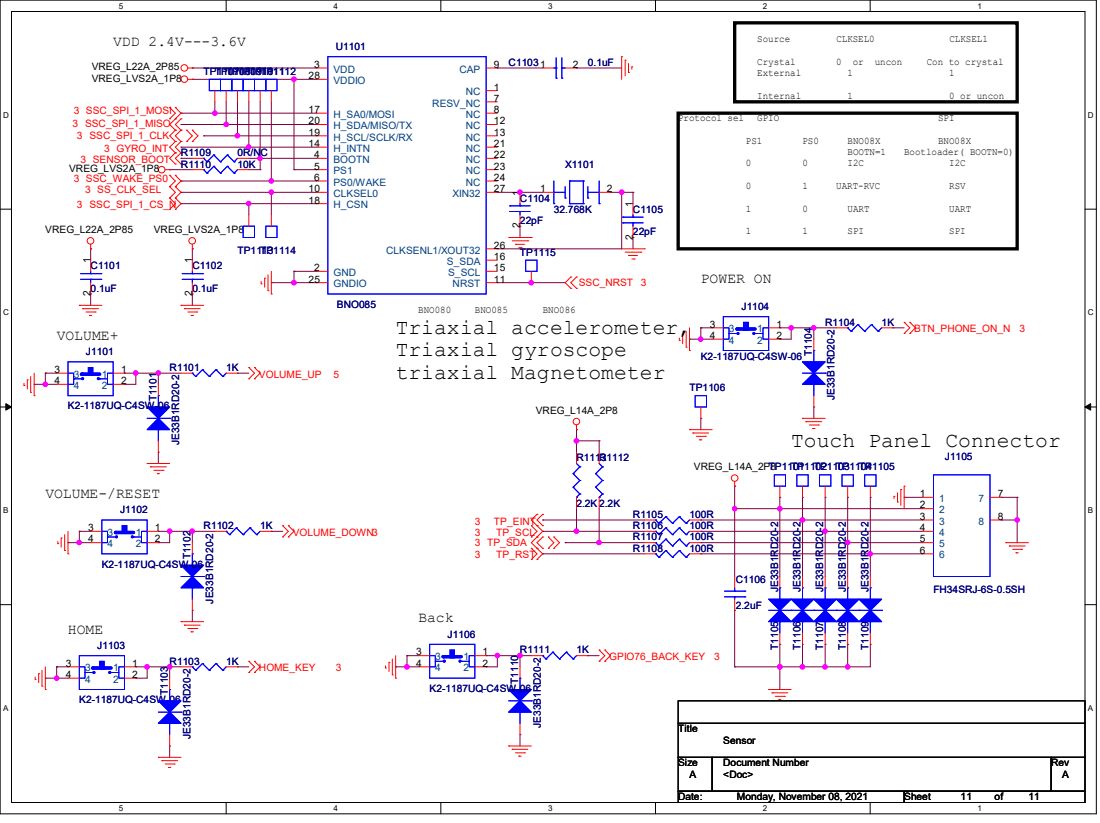
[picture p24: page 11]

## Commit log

2021-03-22 Added Binocular first prototype
    [Model.blend]
2021-03-22 Added display test board incomplete kicad project
    [open-q-820_displays_test_board.kicad_pcb, open-q-820_displays_test_board.sch]
2021-03-22 Added useful docs for open-q 820 board
2021-09-10 Added first kicad export and pdf with eagle schematics
    [BLOCK.sch, BQ25616.sch, Connector.sch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]
2021-09-29 Added BOM from 20210929 for the first prototype
    [bom.csv]
2021-10-15 Updated BOM
    [bom.csv]
2021-10-15 Added BOM sets number and price
    [bom.csv]
2021-12-27 Added converted Video_1028_1.brd through Altium and updated to KiCAD 6
    [BLOCK.kicad_sch, BLOCK.sch, BQ25616.kicad_sch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]
2022-01-14 Added updated prototype 01 test board
    [01_BLOCK.kicad_sch, 02_PWR_FLOW.kicad_sch, 03_Connector.kicad_sch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]
2022-01-14 Added the original testboard design files
    [schema_orcad.dsn]
2022-01-14 Removed the display test board due to general failure of the idea
    [open-q-820_displays_test_board.kicad_pcb, open-q-820_displays_test_board.sch]
2022-01-14 Moved the kicad schematics and cleaned up a bit
    [01_BLOCK.kicad_sch, 02_PWR_FLOW.kicad_sch, 03_Connector.kicad_sch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]
2022-01-14 Added rpm partition modification tool for PM8996 voltages
2022-02-22 Added the steps to flash the required voltages to the board RPM partition
2022-02-22 Added a couple of pictures of connected devboard and in uart mode
2022-02-25 Added the properly working voltages for rpm tool
